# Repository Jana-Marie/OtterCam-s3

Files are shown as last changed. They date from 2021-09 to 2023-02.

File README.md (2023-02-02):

# OtterCam-s3

Open source 1080p60Hz USB & IP camera based on Sochip s3 and OS05A10/OS05A20 (general MIPI CSI IP camera interface).

In the current state the camera does boot and the sensor shows up under linux, however no video or image files have been captured yet, as the sensor driver is currently being written by us. All hardware files are tested in the current revision and are, except for some minor changes, final. Still no waranty as this is an open source project. CAD files have been designed with OpenSCAD and should be final too.

<table>
  <tbody>
    <tr>
      <td>
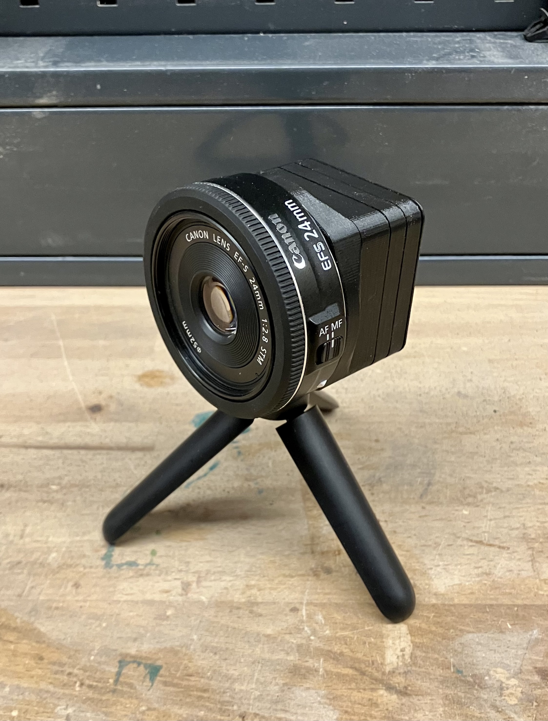
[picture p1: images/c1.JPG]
        
      </td>
      <td>
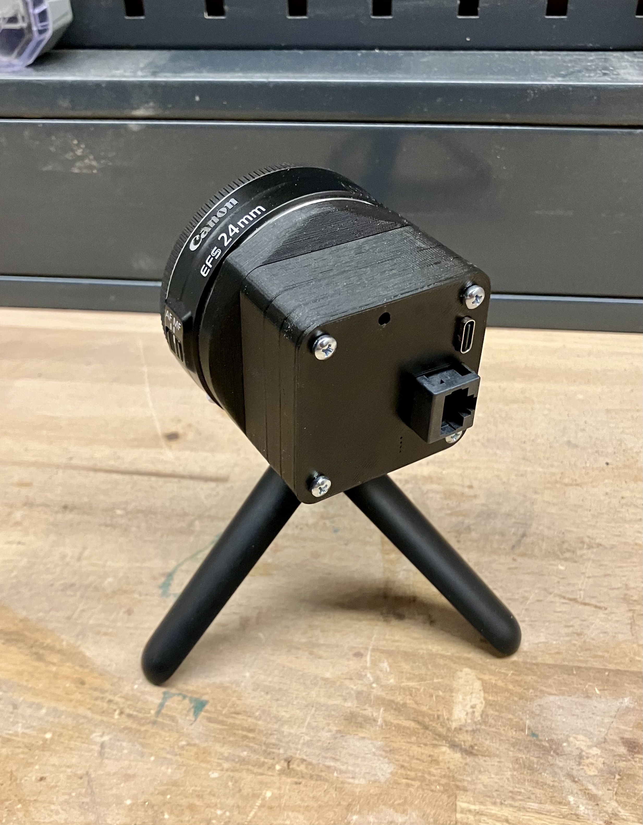
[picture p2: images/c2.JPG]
        
      </td>
    </tr>
    <tr>
      <td colspan="2">
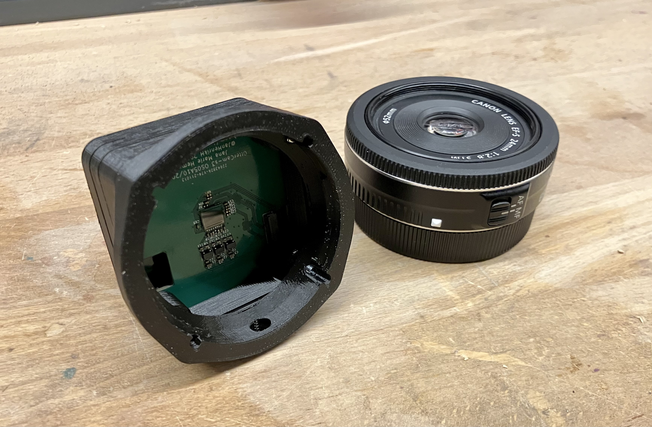
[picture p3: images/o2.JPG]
        
      </td>
    </tr>
    <tr>
      <td>
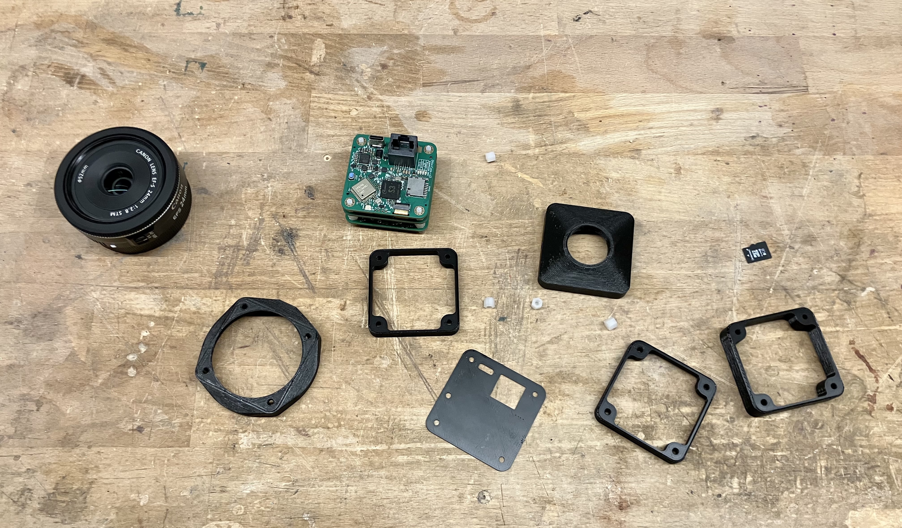
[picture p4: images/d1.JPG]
        
      </td>
      <td>
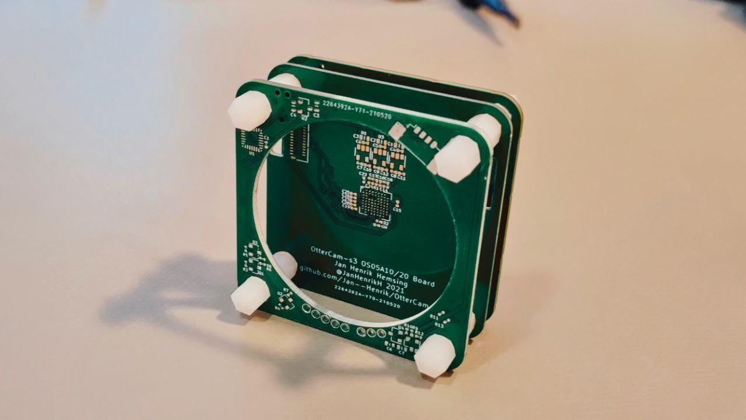
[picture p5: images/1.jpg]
        
      </td>
    </tr>
  </tbody>
</table>

### Todo
 - [ ] Test mipi driver
 - [ ] Build userspace code

### Issues
 - [x] MIPI Lanes Sensor are switched
 - [x] No I2C Pullups

### License

Copyright Jana Marie Hemsing 2023.

This source describes Open Hardware and is licensed under the CERN-OHL-S v2.

You may redistribute and modify this source and make products using it under
the terms of the CERN-OHL-S v2 (https://ohwr.org/cern_ohl_s_v2.txt).

This source is distributed WITHOUT ANY EXPRESS OR IMPLIED WARRANTY,
INCLUDING OF MERCHANTABILITY, SATISFACTORY QUALITY AND FITNESS FOR A
PARTICULAR PURPOSE. Please see the CERN-OHL-S v2 for applicable conditions.

Source location: https://github.com/Jana-Marie/OtterCam-s3

As per CERN-OHL-S v2 section 4, should You produce hardware based on this
source, You must where practicable maintain the Source Location visible
on the external case of the Gizmo or other products you make using this
source.

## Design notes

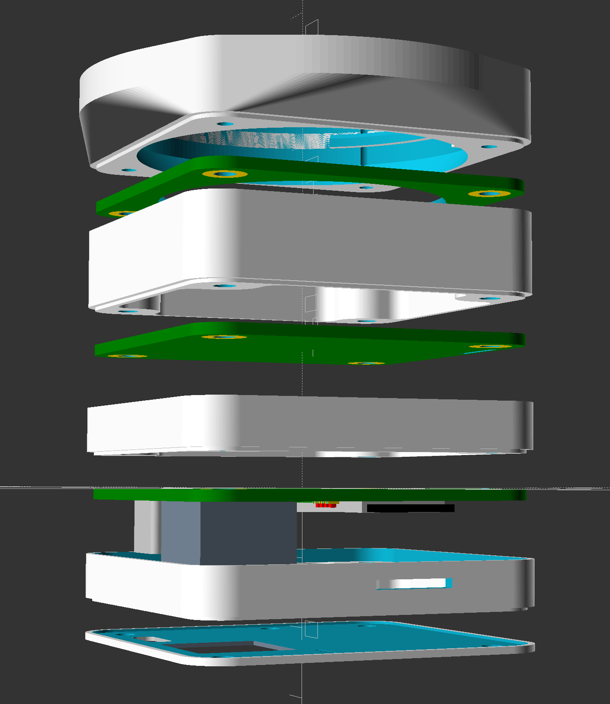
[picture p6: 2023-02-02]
images/render.png

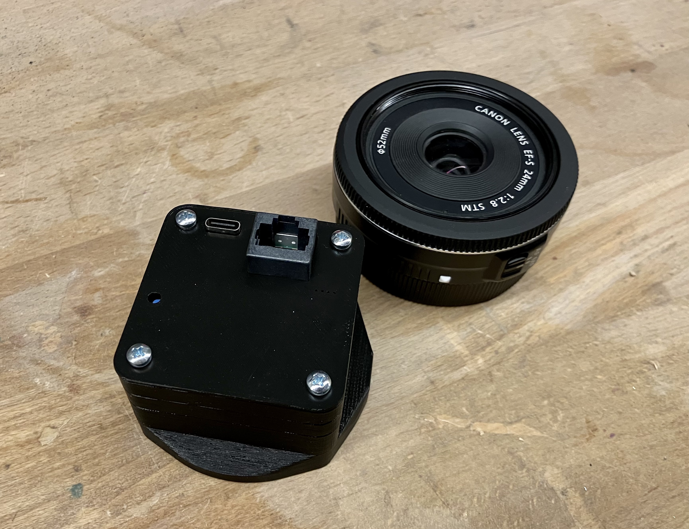
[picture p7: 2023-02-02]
images/o1.JPG

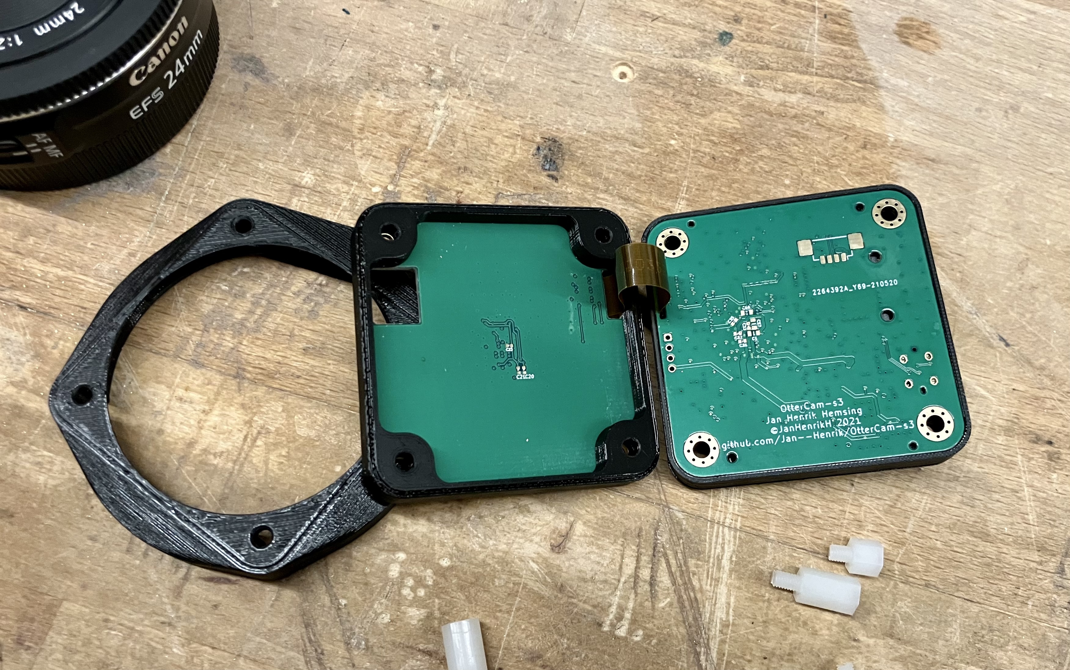
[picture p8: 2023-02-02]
images/d2.JPG

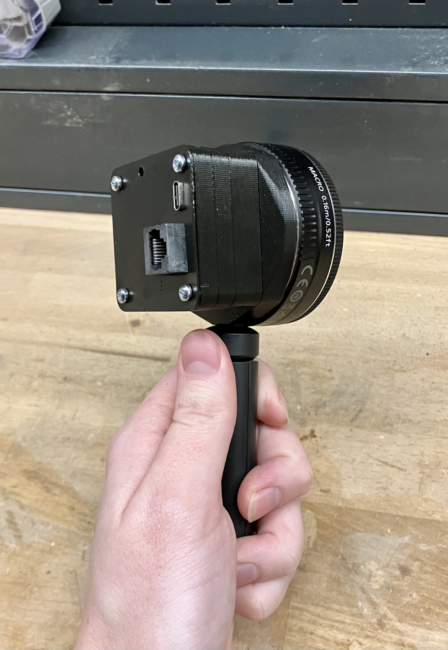
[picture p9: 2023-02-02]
images/c3.JPG

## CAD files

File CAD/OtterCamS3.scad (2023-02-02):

$fn=200;
perim=1;
explode=1;

mount = "efs_mount"; // efs_mount c_mount cs_mount None

if($preview){
    t=1.6;
    if("back_board" && 1){
        translate([0,0,0])back_board(h=t);
    }
    if("sensor_board" && 1){
        translate([0,0,-4.9-t-explode*15])sensor_board(h=t);
    }
    if("shell_b_s" && 1){
        translate([0,0,-4.9-explode*5])shell(h=5,p=perim);
    }

    if("shell_b" && 1){
        translate([0,0,4.9-t-perim-perim/2+explode*10])b_shell(h=4.9,p=perim);
    }
    if("cap_b" && 1){
        translate([0,0,4.9+4.9/2+0.5-perim-perim/2+explode*15])b_cap(h=1,p=perim);
    }
    if(mount == "efs_mount"){
        if("shell_s_l" && 1){
            translate([0,0,-4.9-t-10-explode*20])shell(h=9.9,p=perim);
        }
        if("lens_board" && 1){
            translate([0,0,-4.9-t-10-t-explode*25])lens_board(h=t);
        }
        if("efs_mount" && 1){
            translate([0,0,-4.9-t-9.9-t-t/2-9.9-explode*30])efs_mount();
        }
    }
    if(mount == "c_mount"){
        if("c_mount" && 1){
            translate([0,0,-4.9-t-10-explode*20])c_mount(h=9.9,focus=17.526,sens_h=1,p=perim);
        }
    }
    if(mount == "cs_mount"){
        if("cs_mount" && 1){
            translate([0,0,-2-t-10-explode*20])c_mount(h=7,focus=12.526,sens_h=1,p=perim);
        }
    }
} else {
    c_mount(h=7,focus=12.526,sens_h=1,p=perim);
}

module c_mount(h=10,shoff=0.5,t=1.6,x=49.8,y=49.8,r=4.9,r_d=0.5,p=1,screw=3,focus=17.526,sens_h=1){
    difference(){
        union(){
            difference(){
                union(){
                    for(i = [0:1:3]){
                        // main wall
                       color("white")rotate([0,0,90*i])translate([0,y/2-perim/2,h/2])cube([x-r-r,perim,h],center=true);
                        // screw
                        color("white")rotate([0,0,90*i])hull(){
                            translate([40/2,40/2,0])cylinder(r=r,h=h);
                            translate([x/2-r/2-r,y/2-perim/2,h/2])cube([r,perim,h],center=true);
                            translate([x/2-perim/2,y/2-r/2-r,h/2])cube([perim,r,h],center=true);
                        }
                        // inner diam
                        color("white")rotate([0,0,90*i])
                        difference(){
                            union(){
                                translate([x/2-r-r-r/4,y/2-r/4-perim,h/2])cube([r/2,r/2,h],center=true);
                                translate([x/2-r/4-perim,y/2-r-r-r/4,h/2])cube([r/2,r/2,h],center=true);
                            }
                            union(){
                                translate([x/2-r-r-r/4-r/4,y/2-r/4-perim-r/4,-0.1])cylinder(d=r,h=h+0.2);
                                translate([x/2-r/4-perim-r/4,y/2-r-r-r/4-r/4,-0.1])cylinder(d=r,h=h+0.2);
                            }
                        }
                    }
                    // lenscap
                    color("white")hull(){
                        translate([0,0,-1])minkowski(){
                            cube([x-r-r,y-r-r,3-0.1],center=true);
                            cylinder(r=r+perim,h=0.1);
                        }
                        translate([0,0,h+0.5-focus-sens_h])cylinder(d=30,h=3);
                    }
                }union(){
                    // screw
                    for(i = [-1:2:1]){
                        for(j = [-1:2:1]){
                            translate([i*20,j*20,-0.1])cylinder(d=3.05,h=h+0.2);
                        }
                    }
                    // lenshole
                    translate([0,0,h+0.5-focus-sens_h-0.1])cylinder(d=24.6,h=focus);
                    // lensthread
                    if(!$preview){
                        t_p=0.794;
                        t_h=t_p/2;
                        t_step=12;
                        t_threadstep=t_p/360;
                        translate([0,0,h+0.5-focus-sens_h-0.5])for(i=[0:t_step:360*6]){
                            if(i>0){
                                hull(){
                                    rotate([0,0,i])translate([25.4/2-0.5,0,t_h/2+t_threadstep*i])cube([1.5,0.1,t_h],center=true);
                                    rotate([0,0,i-t_step])translate([25.4/2-0.5,0,t_h/2+t_threadstep*(i-t_step)])cube([1.5,0.1,t_h],center=true);
                                }
                            }
                        }
                    }
                }
            }
            translate([0,0,-shoff])difference() {
                union() {
                    color("white")translate([0,0,h/2-t/2-0.05])minkowski(){
                        cube([x-r-r,y-r-r,h-0.1+t],center=true);
                        cylinder(r=r+perim,h=0.1);
                    }
                }union(){
                    translate([0,0,h/2-t/2-0.1])minkowski(){
                        cube([x-r-r+0.03,y-r-r+0.03,h+t+0.2],center=true);
                        cylinder(r=r,h=0.1);
                    }
                }
            }
            // 1/4"
            c_h=9.5;
            translate([-x/2+(12.7/2),0,-2.75+c_h/2])cube([12.7,12,c_h],center=true);
        }union(){
            // 1/4"
            // https://www.amazon.de/-/en/dp/B09MTS6ZZQ
            rotate([0,90,0])translate([-2.25,0,-x/2-1-0.01])cylinder(d=8,h=12.8); //6.35mm
        }
    }
}

module efs_mount(h=10,shoff=0.5,t=1.6,x=49.8,y=49.8,r=4.9,r_d=0.5,p=1,screw=3){
    difference(){
        union(){
            translate([0,0,h/2+0.5])minkowski(){
                cube([x-r-r,y-r-r,h-0.1],center=true);
                cylinder(r=r,h=0.1);
            }
            hull(){
                hull(){
                    translate([0,0,h/2-0.05])minkowski(){
                        cube([x-r-r,y-r-r,h-0.1],center=true);
                        cylinder(r=r+perim,h=0.1);
                    }
                    translate([0,0,0])cylinder(d=65,h=h/2);
                }
                // mount
                minkowski(){
                    translate([-65/2+1,0,9/2])cube([4-2,12-2,9-2],center=true);
                    sphere(r=1);
                }
            }
        }union(){
            hull(){
                translate([0,0,h])cylinder(d=43.5,h=h/3);
                translate([0,0,-0.1])cylinder(d=54.6,h=6.9+0.2);
            }
            // screw
            for(i = [-1:2:1]){
                for(j = [-1:2:1]){
                    translate([i*20,j*20,-h-0.1])cylinder(d=2.3,h=h*3+0.2);
                }
            }
            // 1/4"
            rotate([0,90,0])translate([-4.5,0,-65/2-1])cylinder(d=5.45,h=6); //6.35mm
            // indicator
            rotate([0,0,112])translate([65/2,0,5/2])rotate([0,0,0])cube([0.3,1.5,1.5],center=true);
        }
    }
    bajonett_angles = [-2, 55.75, 55.75+55.75, 55.75+55.75+54.4, 55.75+55.75+51.4+56.84, 55.75+55.75+51.4+56.84+83.63];
    angle_offset = 0;
    translate([0,0,-0.3])
    difference(){
        union(){
            translate([0,0,1.92])cylinder(d=54.6,h=2.5);
            for(i = [0:2:5]){
                rotate([0,0,bajonett_angles[i]-90])translate([54.6/2-1.4/2,-0.5,2.5/2+2.4+1.92])cube([1.4,1,2.5],center=true);
            }
        }union(){
            translate([0,0,1.92-0.1])cylinder(d=54.6-1.4*2,h=2.5+0.2);
            for(i = [0:2:5]){
                hull(){
                    rotate([0,0,angle_offset+bajonett_angles[i]-90])translate([60/2,0.5,3])cube([20,1,6],center=true);
                    rotate([0,0,angle_offset+bajonett_angles[i+1]-90])translate([60/2,-0.5,3])cube([20,1,6],center=true);
                }
            }
            translate([0,0,-1])cylinder(d1=65,d2=0,h=20);
        }
    }
}
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

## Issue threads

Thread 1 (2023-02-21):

Firmware

EmmanuelP, 2023-02-21:
Hi Jana-Marie,

Interesting project. Do you plan to also open source the firmware ?

I'm the maintainer of the Aravis project, an open source implementation of GiGEVision and USB3Vision protocols. If time permits, I'd like to try to implement the camera part of one of these protocols for the OtterCam.

Emmanuel.

Jana-Marie, 2023-02-22:
Hey Emmanuel! Yea I plan to Open Source everything, include FW and all build sources. It sadly just isn't there yet.
The Linux boots already and shows the sensor on the I2C bus, and has a ready to receive MIPI driver. However userspace software sending the right I2C commands is missing, we are working on that!

I would love to have the OtterCam-s3 (another OtterCam with NDI is in the works. It has the FW, Linux and HDL ready, but is missing the HW. The OtterCam-s3 is a HW sanity check and the cheaper variant of it.) added to aravis! I stumbled across your library just a few days ago, trying to revive a SVS-Vistek GigE cam. Fantastic work! :3

Jana-Marie, 2023-05-04:
Bump: We are still working on it, sorry for all the delay 🙈

Alan01252, 2024-06-12:
As someone about to potentially embark on a similar journey, how did you get on :)?

Jana-Marie, 2024-06-12:
Honestly, we didn't. Didn't yet, although what is that yet worth. I haven't given up on the OtterCamS3, but I also haven't worked on it in a while. We lost all momentum and haven't regained it yet, so I'm afraid there is no good answer to "how did you get on" :/

peteallenm, 2024-06-17:
I'm very interested in this.
I've got some very relevant experience-I've written a mipi driver for S3 with hdzero cameras (drone cameras with mipi csi yuyv output).
I'm looking for better sensors (hdzero is 720/60) and so was looking at these omnivision sensors.
Do you want to collaborate?

Jana-Marie, 2024-06-18:
Hey all and @peteallenm,

Thank you so much for your interest, collaboration would be highly welcome :3

As it seems, we need to tackle the following tasks next:

- write a driver for the OS05A10/A20
- write userspace software
  - something that does the peripheral -> stream transport
  - V4l to I2C for the OS05A10/A20
  - Maybe a web-ui for further configuration

There is actually already a working fork of the OtterCam3, which already addresses the driver + stream issue 🙈 We will try to incorporate it back into the OtterCamS3, leaving us with less and easier issues to work on. https://gregdavill.com/posts/allwinner-s3-videoencoders/

I'm away until mid-July. Your interest motivates me to work on this project again, I will return to it in July and I will try to get it to a working point. I'm not entirely sure how further collaboration works the best, any ideas?

~ Jana

peteallenm, 2024-06-23:
Have you got a datasheet for the OS05A10?
One of the first things with the driver is to set up the (MIPI) bus format, and that is not easy without the datasheet.
I also presume you are using the onboard ISP, so intending to get the sensor to give you what it describes as RGB? I haven't looked into the S3 ISP at all, but understand debayering should be possible, but tuning the ISP for a sensor is out of reach for hobbyists, so the onboard ISP makes a lot of sense.
The datasheet for OS08A20 (same range, different sensor) mentions YUV420p output (which would be ideal), but not anything about specifics of it. The OS05A20 drivers I've seen on github confuse me a little as they seem to be bayer output, which is not ideal, but I've only looked at a couple.
Just FYI I had to fix a load of bugs in the MIPI driver for YUYV formats on S3.

 It's pretty easy to send I2C from userspace... i2cset is your friend.

peteallenm, 2024-06-23:
Oh - you mentioned getting raw images out:
v4l2-ctl --set-fmt-video=width=1280,height=720,pixelformat=NV12 --stream-mmap --stream-count=1 -d /dev/video0 --stream-to=CamOutNV12.raw
Obviously change the video format to suit.

Can you point me to the working fork of ottercam 3? I am pretty interested

Jana-Marie, 2024-07-19:
Thanks! I will try that! I havent gotten around to working on it yet, sorry for that. I'm not sure if the/a working fork is pushed somewhere being honest, I will check

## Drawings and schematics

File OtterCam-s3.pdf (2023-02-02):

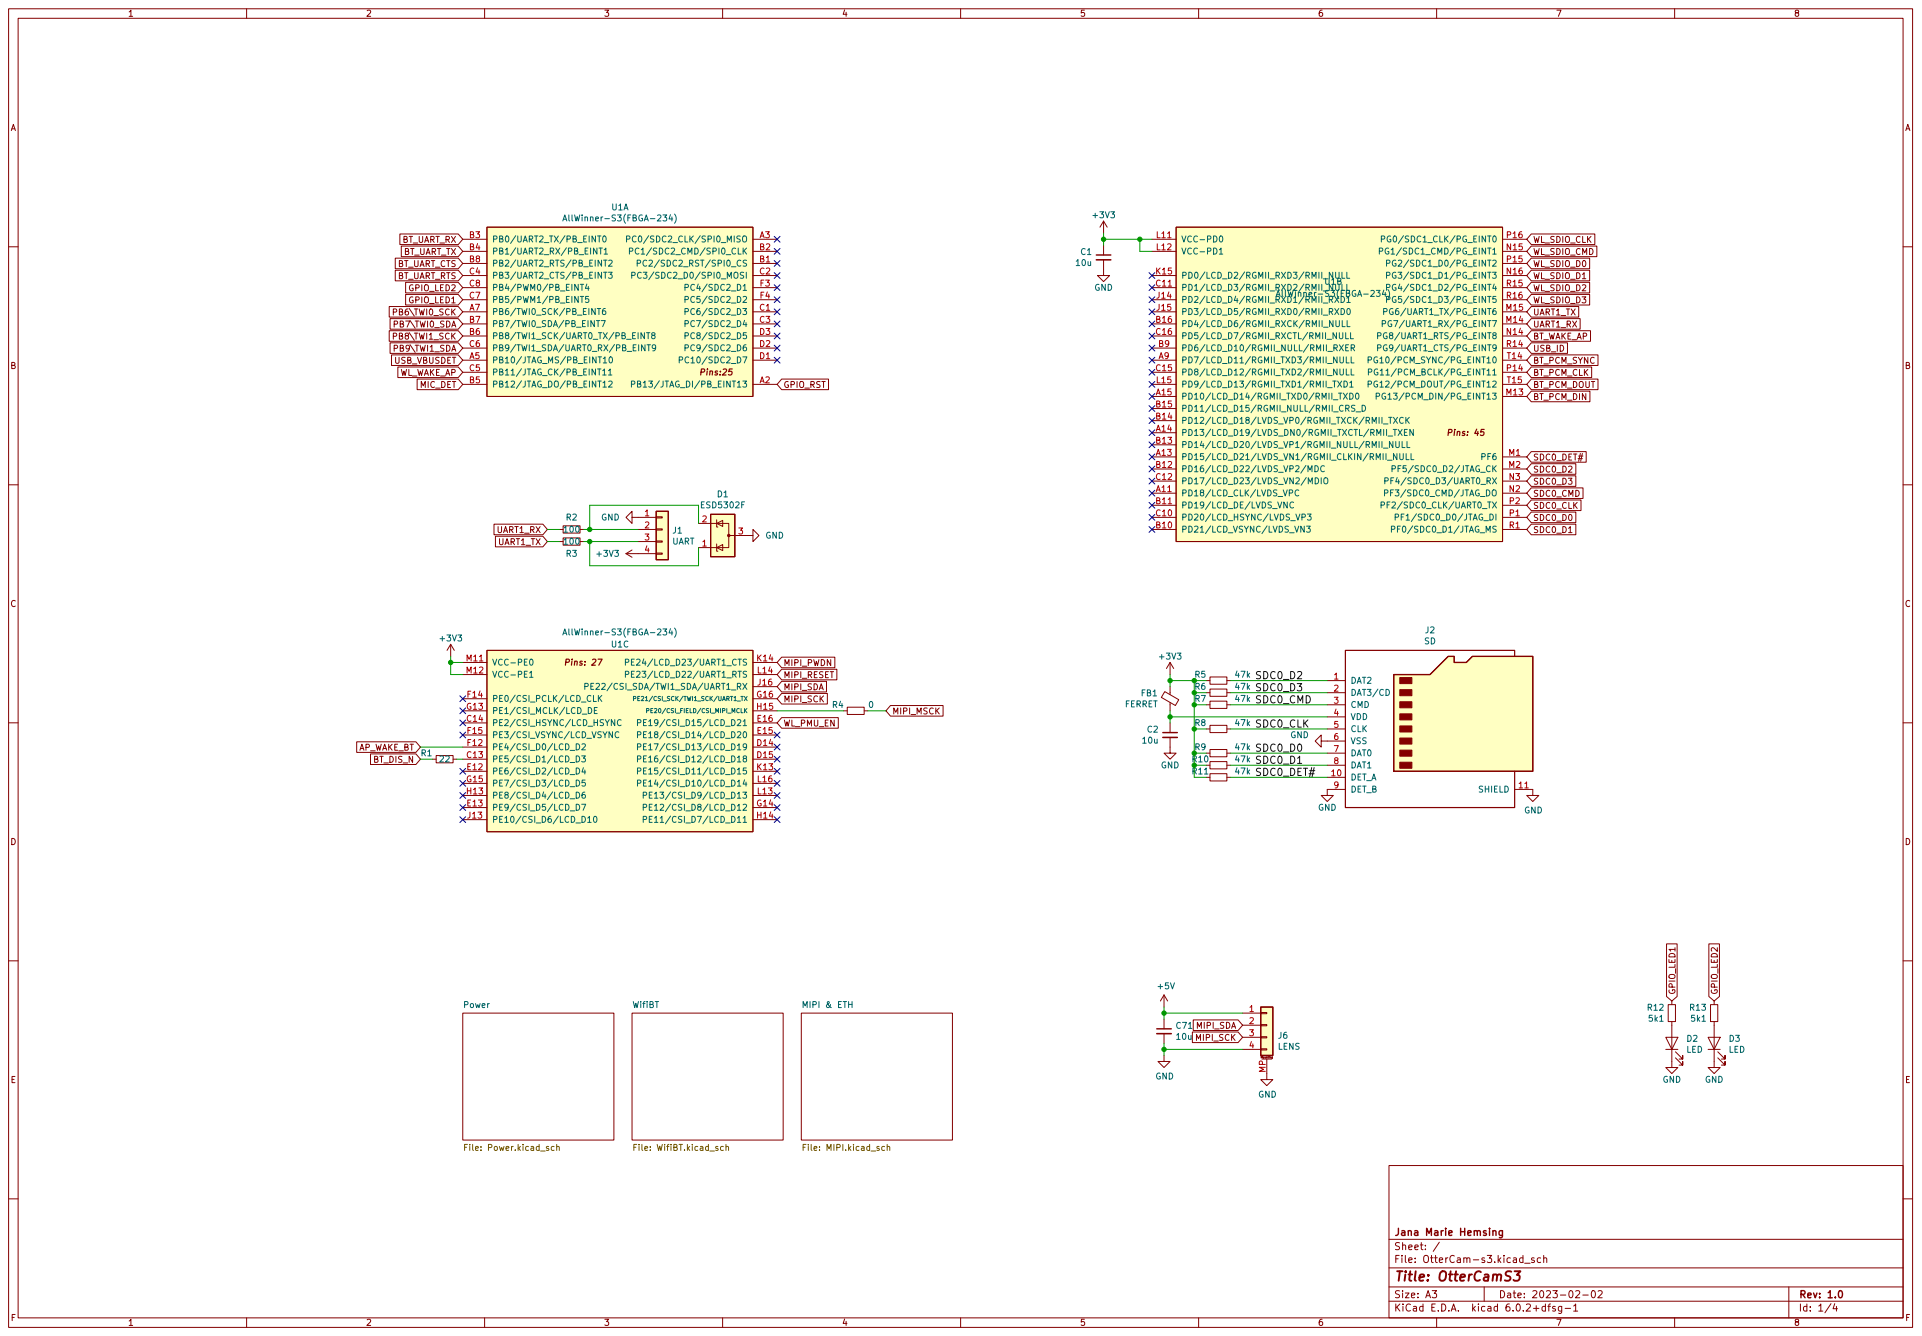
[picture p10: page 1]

File: OtterCam-s3.kicad_sch Sheet: / Jana Marie Hemsing MIPI & ETH

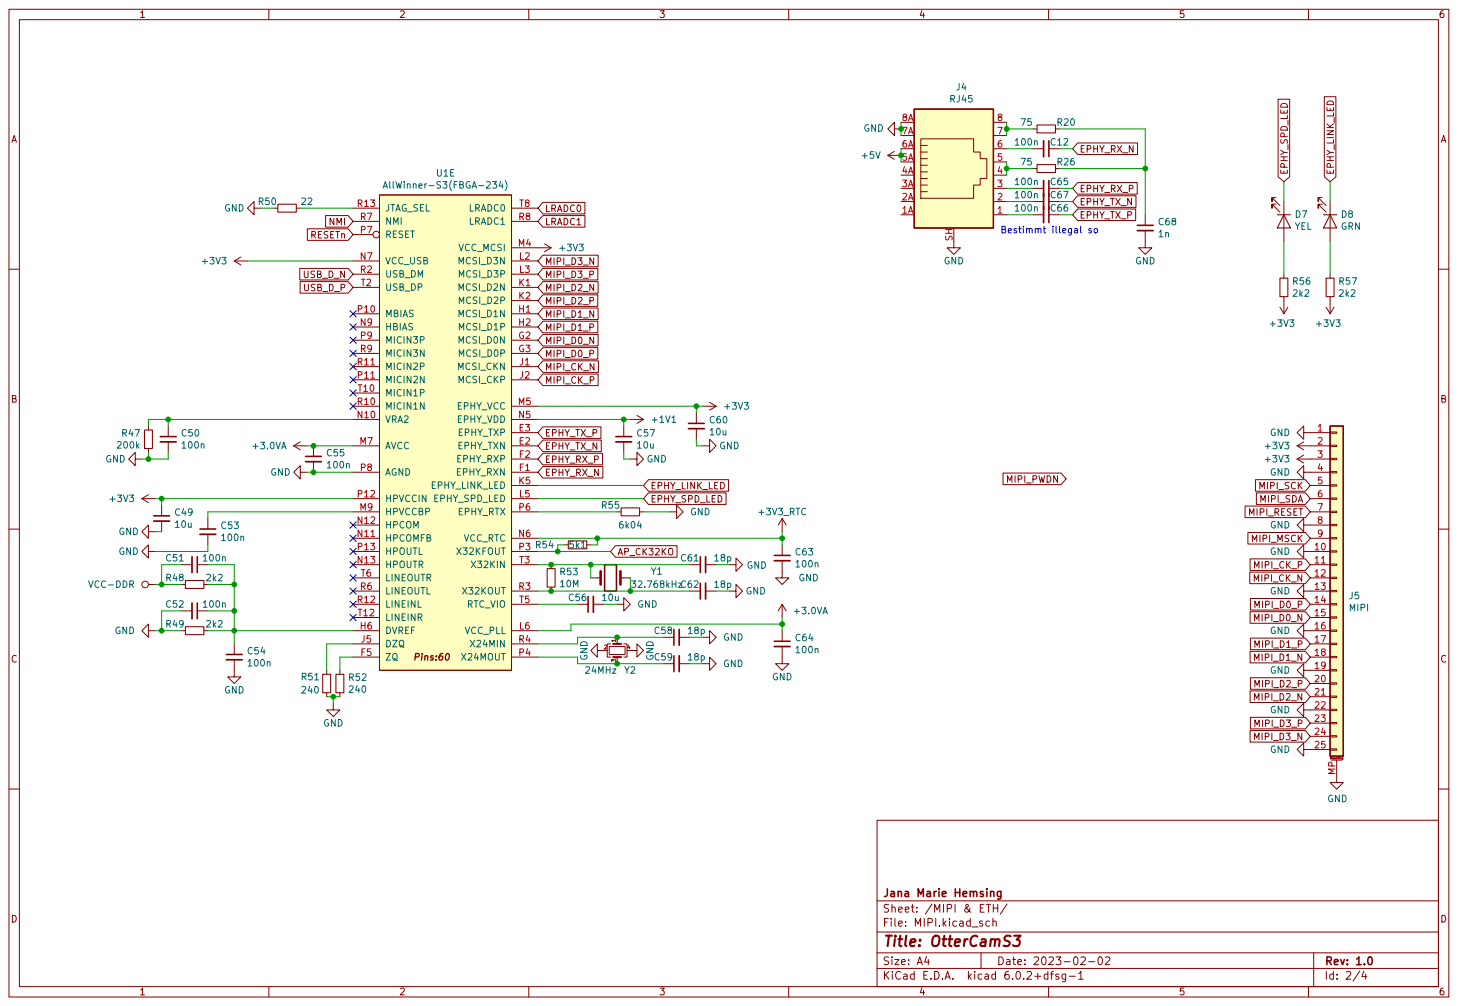
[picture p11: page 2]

File: MIPI.kicad_sch Sheet: /MIPI & ETH/ Jana Marie Hemsing GND

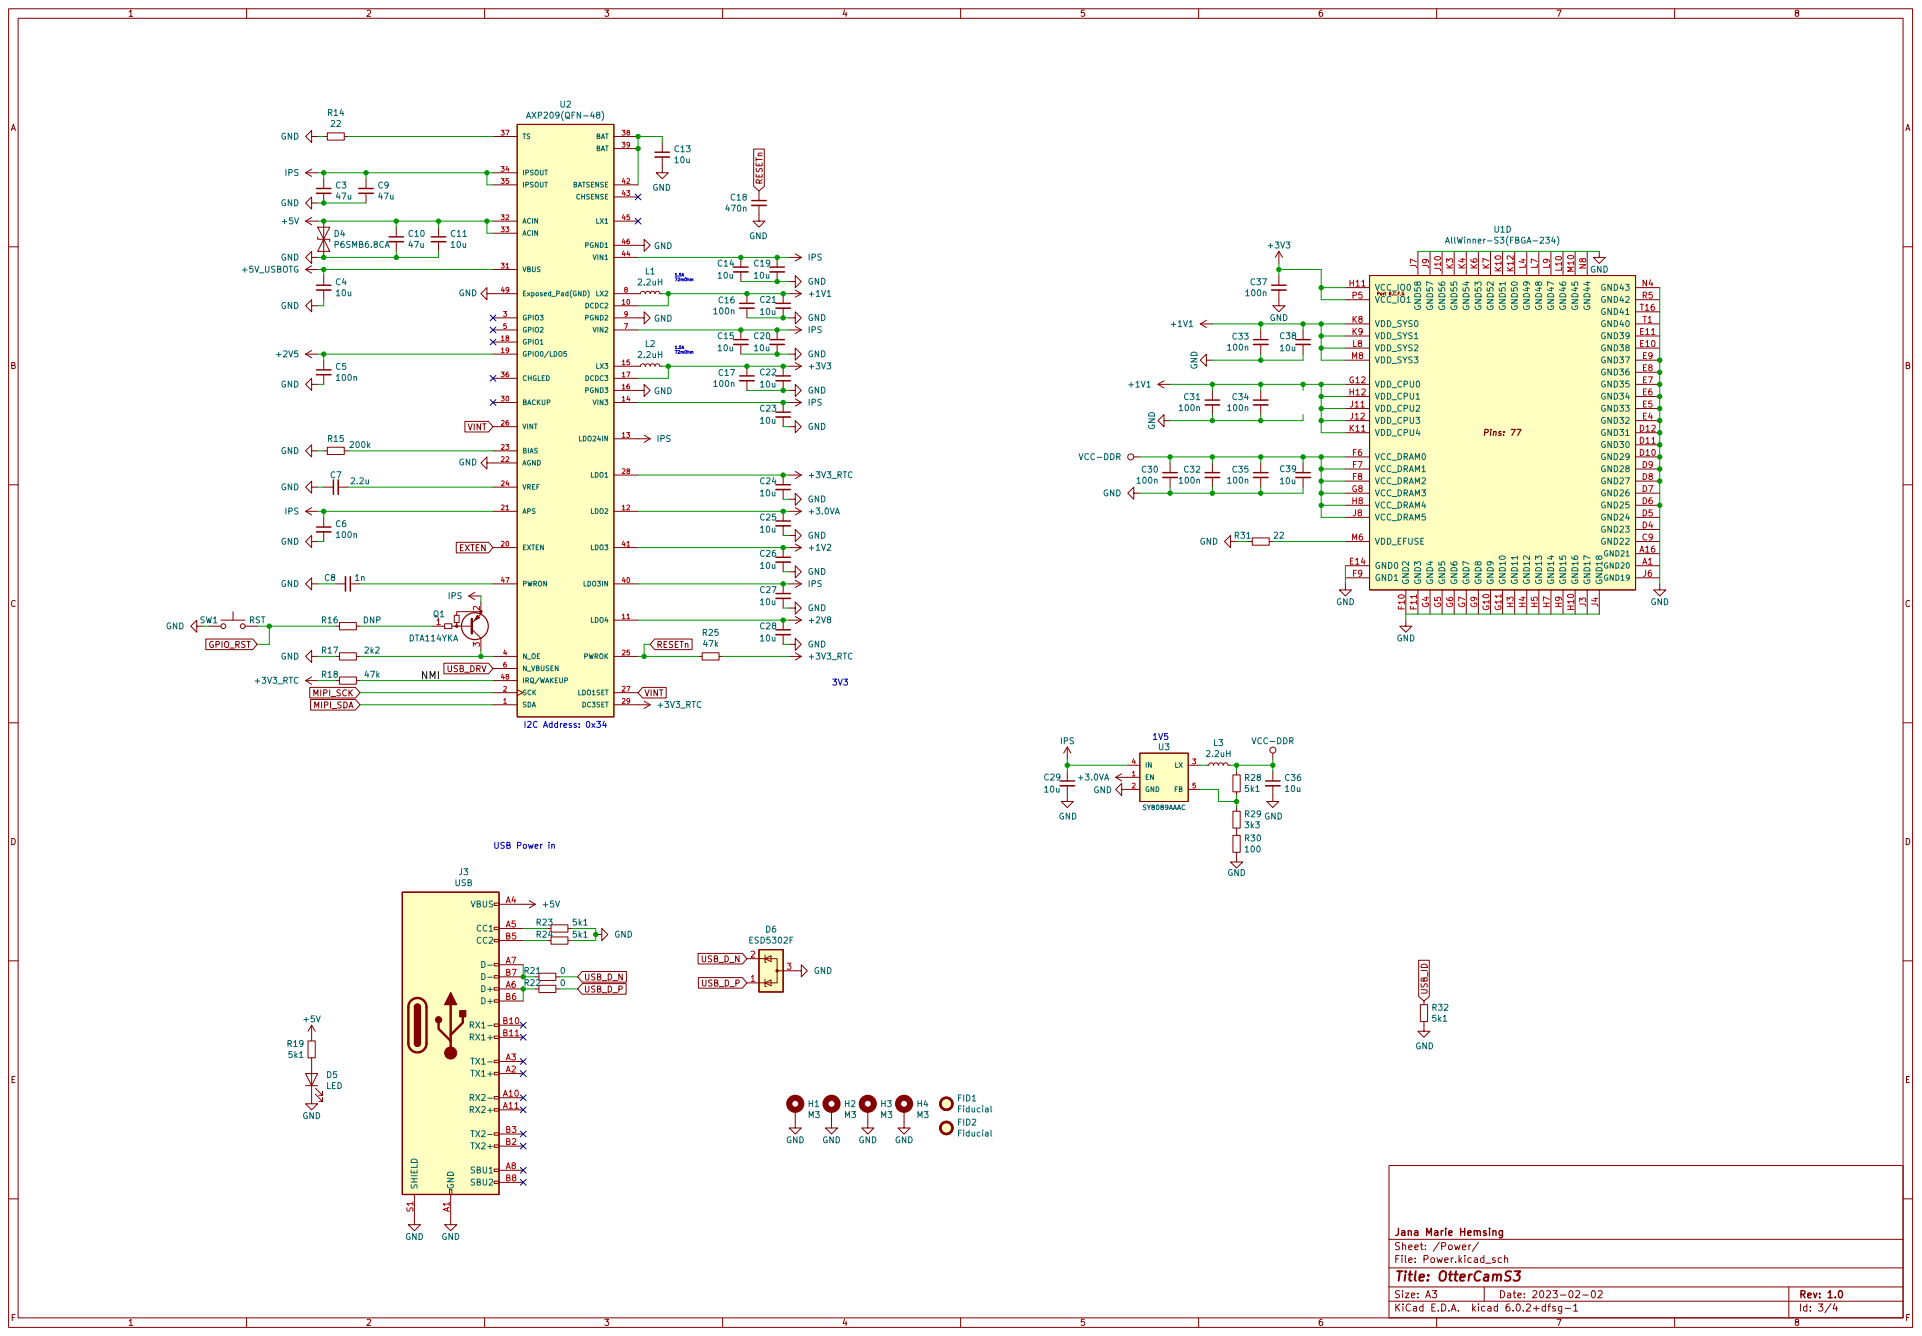
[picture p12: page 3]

I2C Address: 0x34 USB Power in

File: Power.kicad_sch Sheet: /Power/ Jana Marie Hemsing

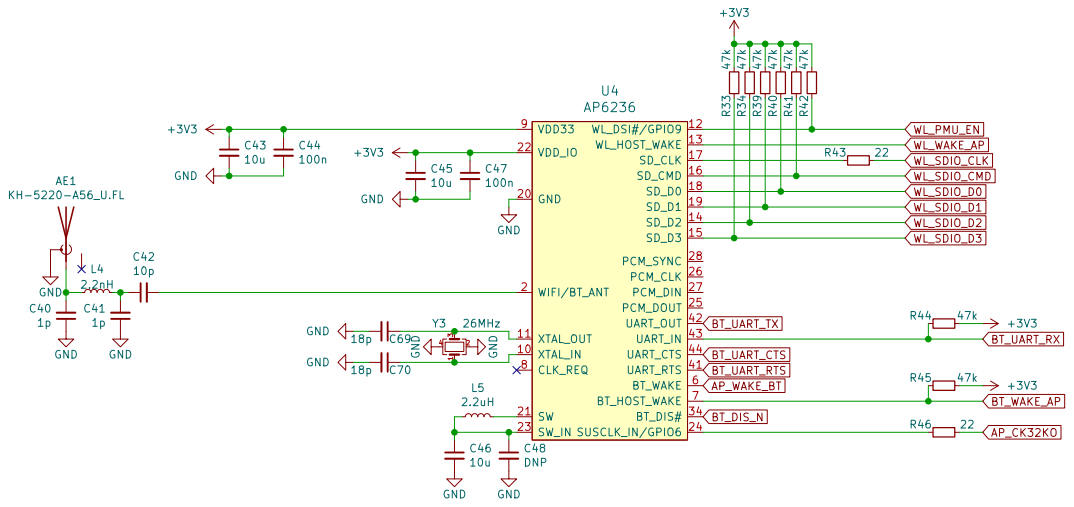
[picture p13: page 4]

File: WifiBT.kicad_sch Sheet: /WifiBT/ Jana Marie Hemsing C42

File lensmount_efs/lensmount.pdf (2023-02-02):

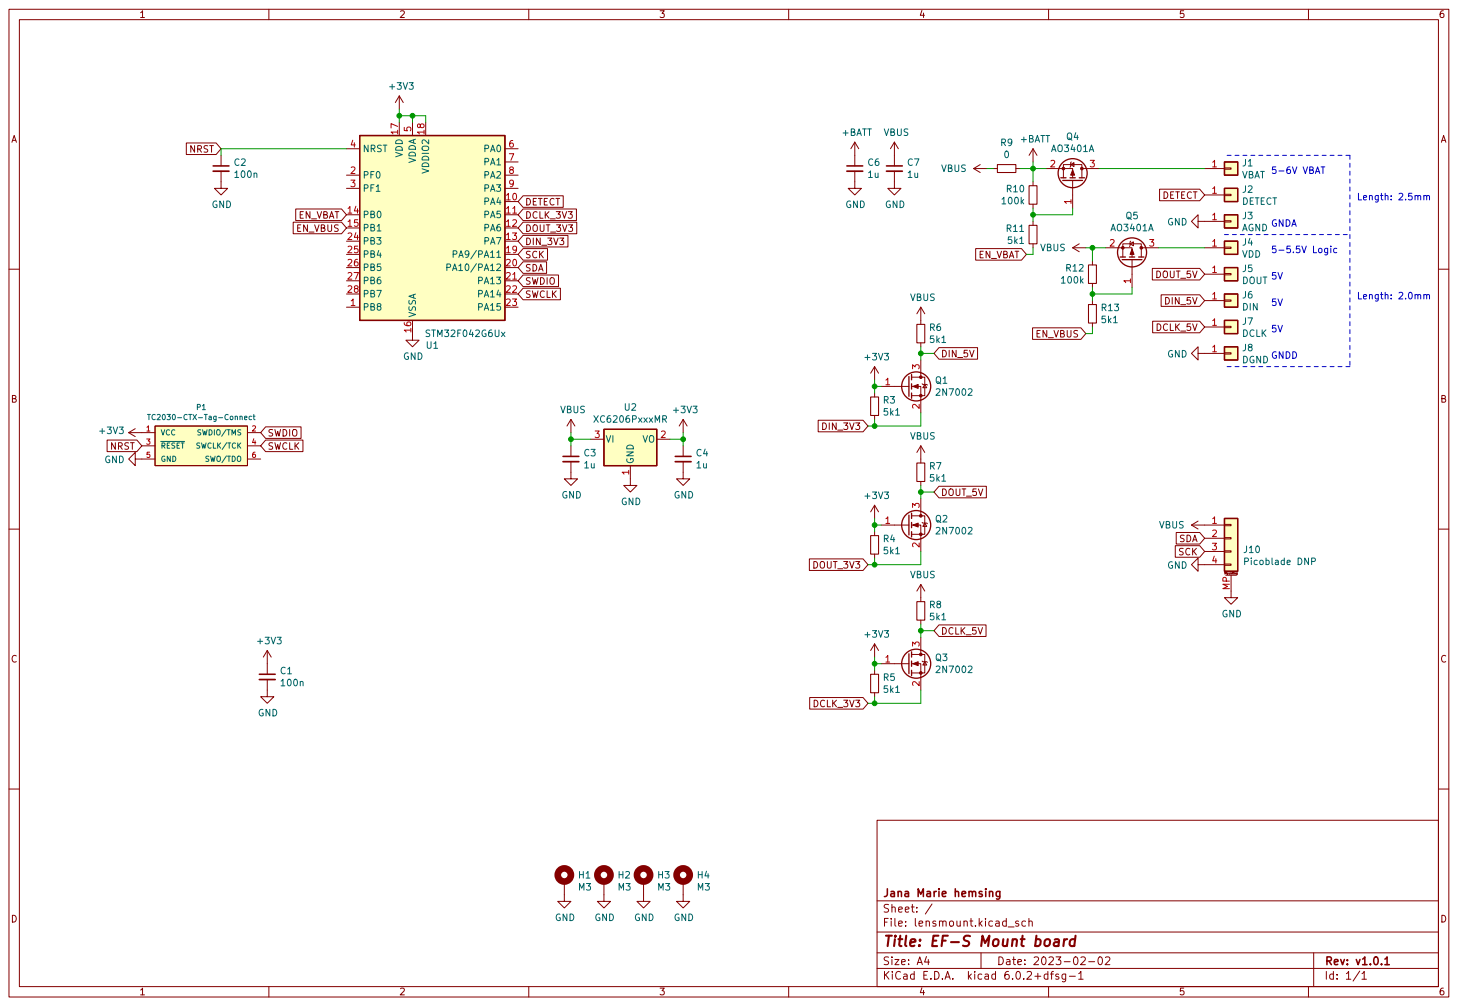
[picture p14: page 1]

1 VO 2 VI 3 U2 XC6206PxxxMR GND GND
VBUSC3

File: lensmount.kicad_sch Sheet: / Jana Marie hemsing C1

Id: 1/1 Title: EF-S Mount board

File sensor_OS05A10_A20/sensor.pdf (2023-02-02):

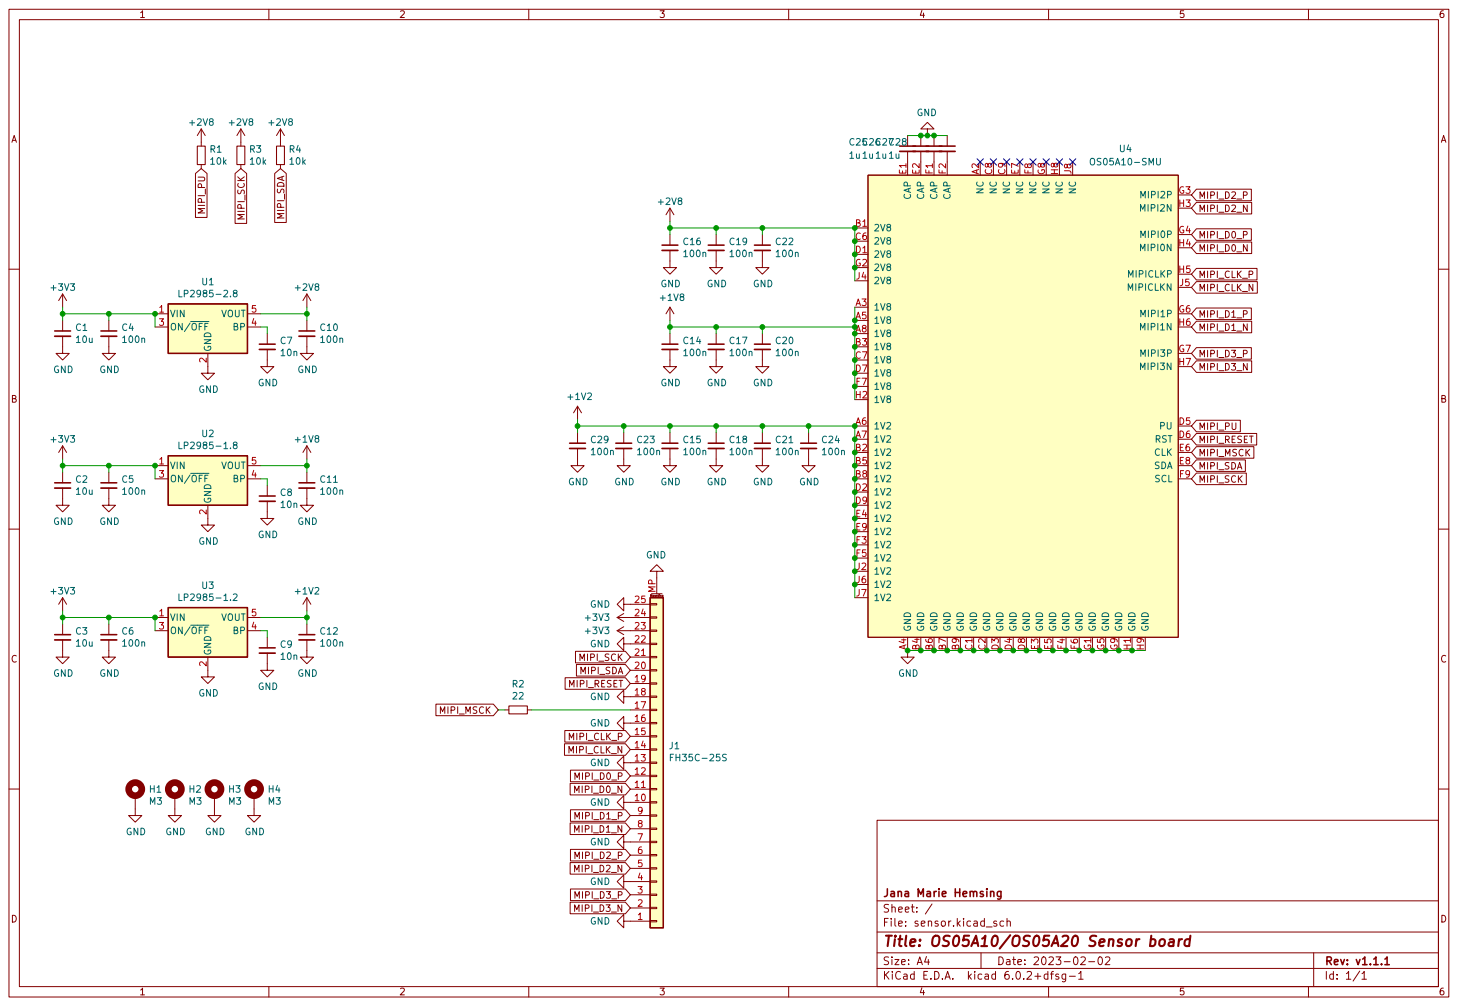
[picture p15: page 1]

File: sensor.kicad_sch Sheet: / Jana Marie Hemsing

Id: 1/1 Title: OS05A10/OS05A20 Sensor board

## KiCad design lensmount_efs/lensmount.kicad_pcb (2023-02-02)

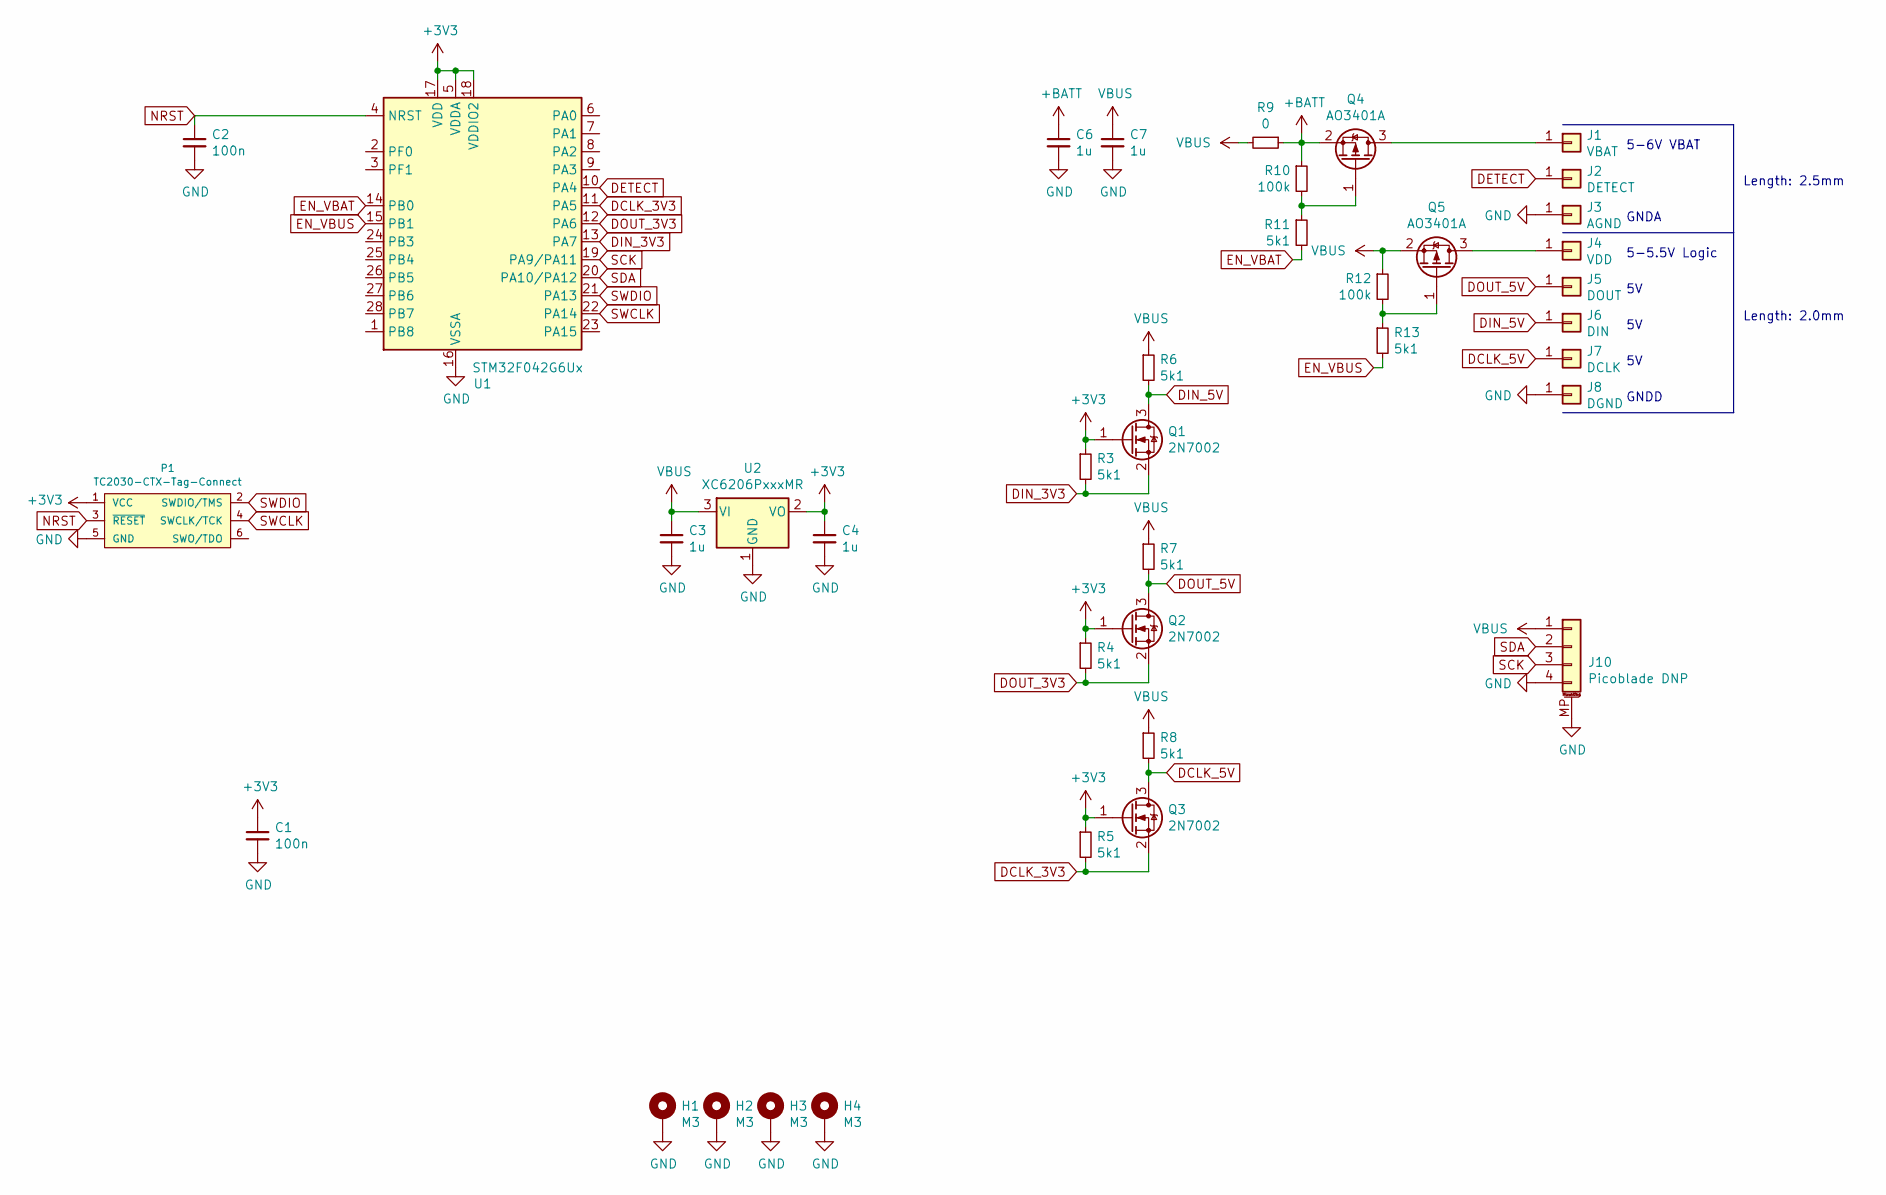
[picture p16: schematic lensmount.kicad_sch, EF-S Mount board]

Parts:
C1, C2: 100n; C_0402
C3, C4, C6, C7: 1u; C_0603
H1, H2, H3, H4: M3; MountingHole_3mm_Pad_Via
J1: VBAT; PH-MVF-5365; Mouser 581-709150001025006
J2: DETECT; PH-MVF-5365; Mouser 581-709150001025006
J3: AGND; PH-MVF-5365; Mouser 581-709150001025006
J4: VDD; PH-MVF-5365; Mouser 581-709150001020006
J5: DOUT; PH-MVF-5365; Mouser 581-709150001020006
J6: DIN; PH-MVF-5365; Mouser 581-709150001020006
J7: DCLK; PH-MVF-5365; Mouser 581-709150001020006
J8: DGND; PH-MVF-5365; Mouser 581-709150001020006
J10: Picoblade DNP; Molex_PicoBlade_53398-0471_1x04-1MP_P1.25mm_Vertical
P1: TC2030-CTX-Tag-Connect; TC2030
Q1, Q2, Q3: 2N7002; SOT-23
Q4, Q5: AO3401A; SOT-23
R3, R4, R5, R6, R7, R8, R11, R13: 5k1; R_0402
R9: 0; R_0402
R10, R12: 100k; R_0402
U1: STM32F042G6Ux; QFN-28_4x4mm_P0.5mm
U2: XC6206PxxxMR; SOT-23

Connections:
+3V3: C1.1, C4.1, P1.1 (VCC), Q1.1 (G), Q2.1 (G), Q3.1 (G), R3.1, R4.1, R5.1, U1.5 (VDDA), U1.17 (VDD), U1.18 (VDDIO2), U2.2 (VO)
+BATT: C6.1, Q4.2 (S), R9.1, R10.1
DCLK_3V3: Q3.2 (S), R5.2, U1.11 (PA5)
DCLK_5V: J7.1, Q3.3 (D), R8.2
DETECT: J2.1, U1.10 (PA4)
DIN_3V3: Q1.2 (S), R3.2, U1.13 (PA7)
DIN_5V: J6.1, Q1.3 (D), R6.2
DOUT_3V3: Q2.2 (S), R4.2, U1.12 (PA6)
DOUT_5V: J5.1, Q2.3 (D), R7.2
EN_VBAT: R11.2, U1.14 (PB0)
EN_VBUS: R13.2, U1.15 (PB1)
GND: C1.2, C2.2, C3.2, C4.2, C6.2, C7.2, H1.1, H2.1, H3.1, H4.1, J3.1, J8.1, J10.4, J10.MP (MountPin), P1.5 (GND), U1.16 (VSSA), U2.1 (GND)
NRST: C2.1, P1.3 (~RESET), U1.4 (NRST)
unnamed: J1.1, Q4.3 (D)
unnamed: J4.1, Q5.3 (D)
unnamed: Q4.1 (G), R10.2, R11.1
unnamed: Q5.1 (G), R12.2, R13.1
SCK: J10.3, U1.19 (PA9/PA11)
SDA: J10.2, U1.20 (PA10/PA12)
SWCLK: P1.4 (SWCLK/TCK), U1.22 (PA14)
SWDIO: P1.2 (SWDIO/TMS), U1.21 (PA13)
VBUS: C3.1, C7.1, J10.1, Q5.2 (S), R6.1, R7.1, R8.1, R9.2, R12.1, U2.3 (VI)

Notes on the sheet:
GNDD
5-6V VBAT
Length: 2.5mm
5-5.5V Logic
GNDA
Length: 2.0mm

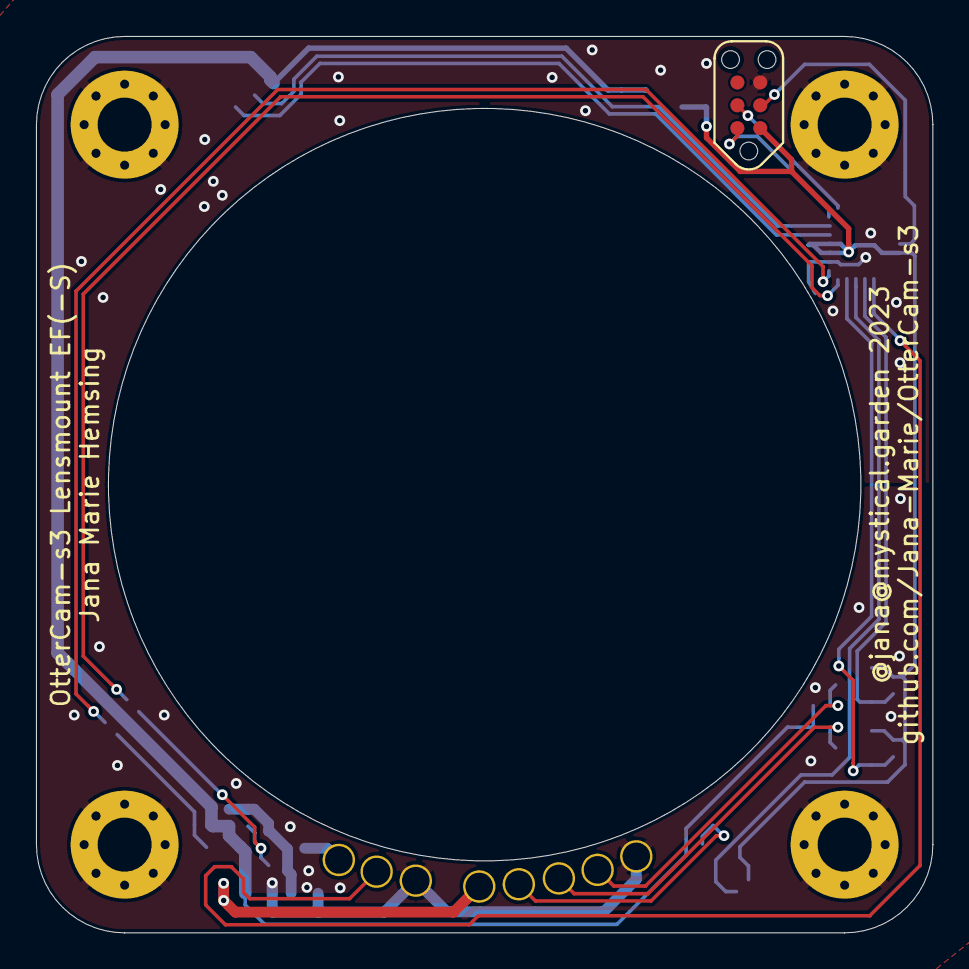
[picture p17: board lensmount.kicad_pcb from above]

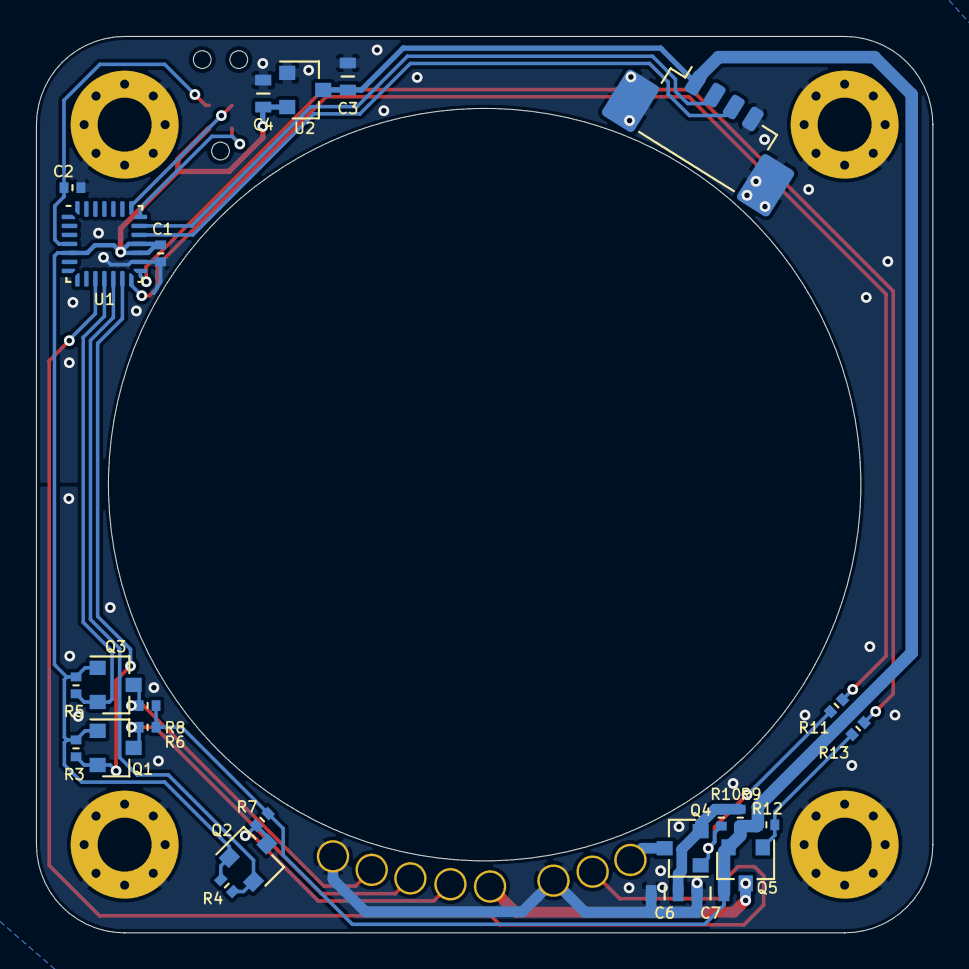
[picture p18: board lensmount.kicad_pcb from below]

Board: 2 copper layers, 49.8 x 49.8 mm, 38 parts (25 on the bottom side), 22 nets.

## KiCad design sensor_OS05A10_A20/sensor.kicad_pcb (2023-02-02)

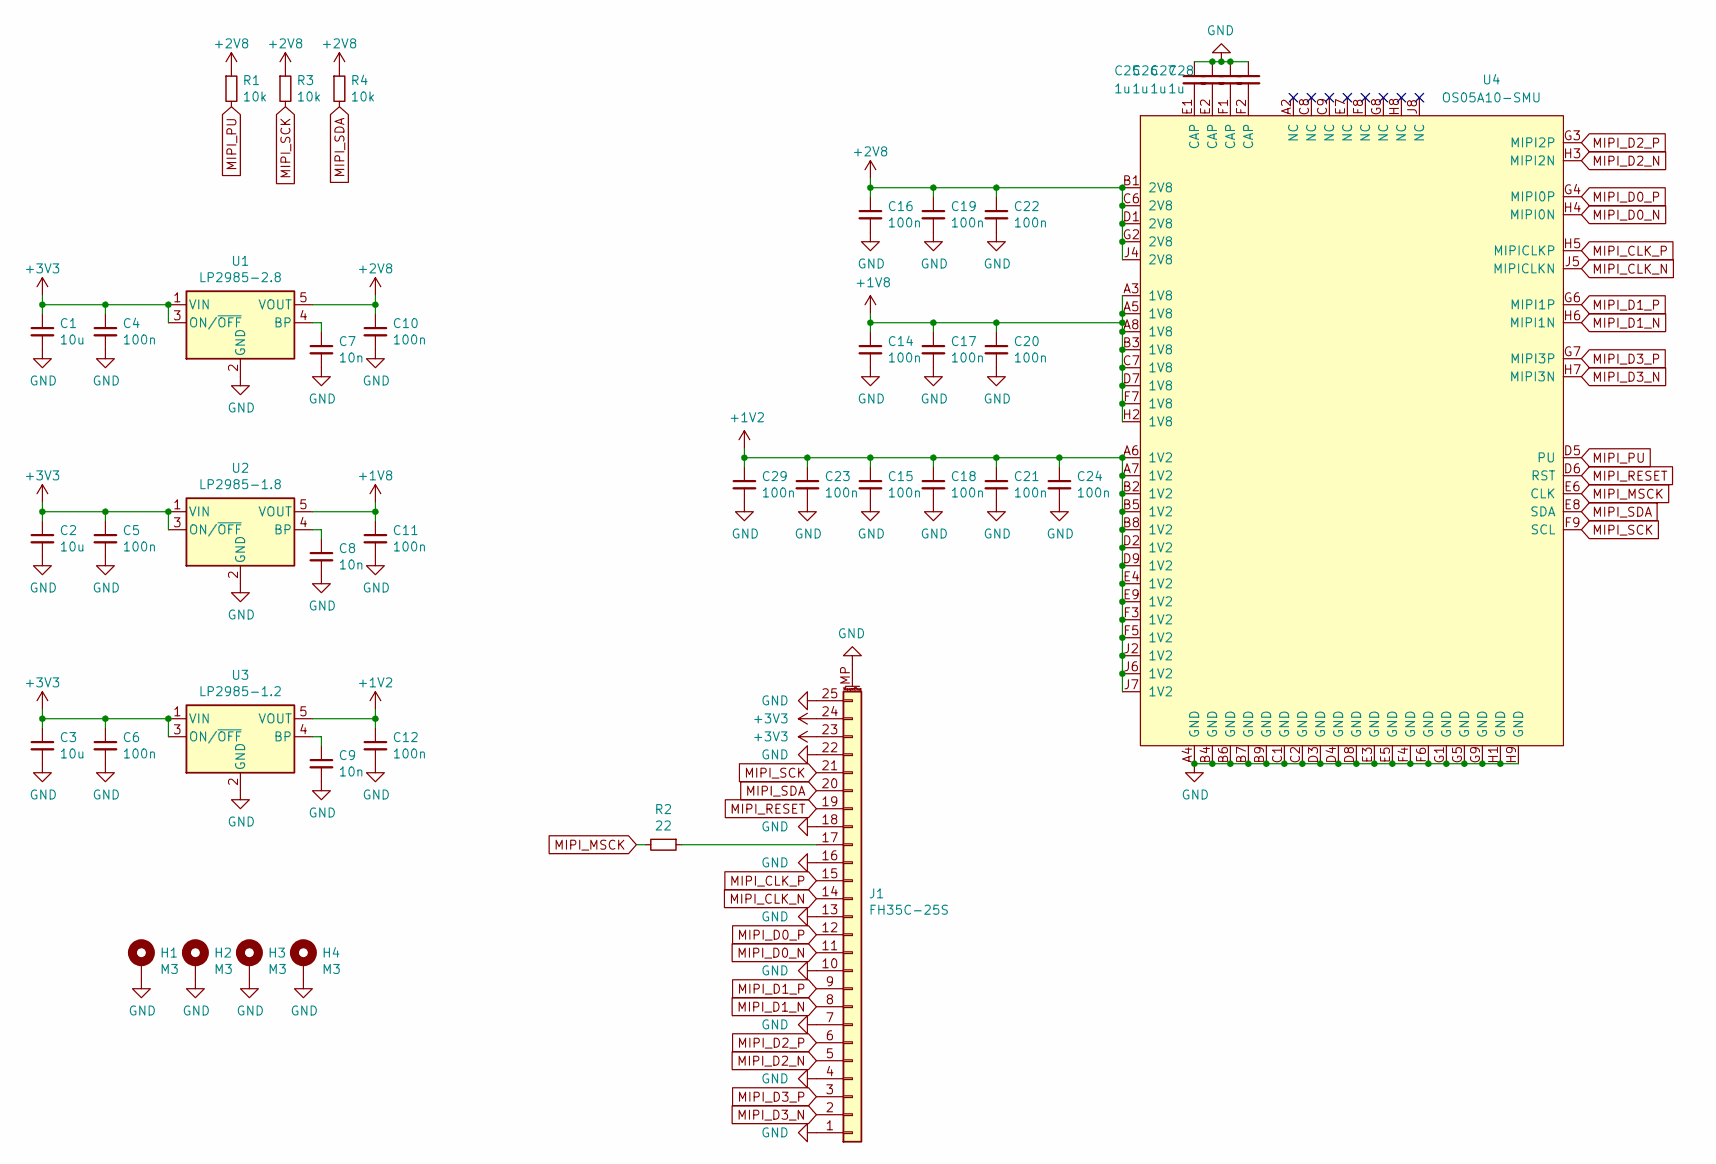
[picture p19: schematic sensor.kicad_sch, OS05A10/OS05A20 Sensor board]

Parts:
C1, C2, C3: 10u; C_0603
C4, C5, C6, C10, C11, C12, C14, C15, C16, C17, C18, C19, C20, C21, C22, C23, C24, C29: 100n; C_0402
C7, C8, C9: 10n; C_0402
C25, C26, C27, C28: 1u; C_0402
H1, H2, H3, H4: M3; MountingHole_3mm_Pad_Via
J1: FH35C-25S
R1, R3, R4: 10k; R_0402
R2: 22; R_0402
U1: LP2985-2.8; SOT-23-5
U2: LP2985-1.8; SOT-23-5
U3: LP2985-1.2; SOT-23-5
U4: OS05A10-SMU; OS05A10

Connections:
+1V2: C12.1, C15.1, C18.1, C21.1, C23.1, C24.1, C29.1, U3.5 (VOUT), U4.A6 (1V2), U4.A7 (1V2), U4.B2 (1V2), U4.B5 (1V2), U4.B8 (1V2), U4.D2 (1V2), U4.D9 (1V2), U4.E4 (1V2), U4.E9 (1V2), U4.F3 (1V2), U4.F5 (1V2), U4.J2 (1V2), U4.J6 (1V2), U4.J7 (1V2)
+1V8: C11.1, C14.1, C17.1, C20.1, U2.5 (VOUT), U4.A3 (1V8), U4.A5 (1V8), U4.A8 (1V8), U4.B3 (1V8), U4.C7 (1V8), U4.D7 (1V8), U4.F7 (1V8), U4.H2 (1V8)
+2V8: C10.1, C16.1, C19.1, C22.1, R1.1, R3.1, R4.1, U1.5 (VOUT), U4.B1 (2V8), U4.C6 (2V8), U4.D1 (2V8), U4.G2 (2V8), U4.J4 (2V8)
+3V3: C1.1, C2.1, C3.1, C4.1, C5.1, C6.1, J1.23, J1.24, U1.1 (VIN), U1.3 (ON/~OFF), U2.1 (VIN), U2.3 (ON/~OFF), U3.1 (VIN), U3.3 (ON/~OFF)
GND: C1.2, C2.2, C3.2, C4.2, C5.2, C6.2, C7.2, C8.2, C9.2, C10.2, C11.2, C12.2, C14.2, C15.2, C16.2, C17.2, C18.2, C19.2, C20.2, C21.2, C22.2, C23.2, C24.2, C25.1, C26.1, C27.1, C28.1, C29.2, H1.1, H2.1, H3.1, H4.1, J1.1, J1.4, J1.7, J1.10, J1.13, J1.16, J1.18, J1.22, J1.25, J1.MP (MountPin), U1.2 (GND), U2.2 (GND), U3.2 (GND), U4.A4 (GND), U4.B4 (GND), U4.B6 (GND), U4.B7 (GND), U4.B9 (GND), U4.C1 (GND), U4.C2 (GND), U4.D3 (GND), U4.D4 (GND), U4.D8 (GND), U4.E3 (GND), U4.E5 (GND), U4.F4 (GND), U4.F6 (GND), U4.G1 (GND), U4.G5 (GND), U4.G9 (GND), U4.H1 (GND), U4.H9 (GND)
MIPI_CLK_N: J1.14, U4.J5 (MIPICLKN)
MIPI_CLK_P: J1.15, U4.H5 (MIPICLKP)
MIPI_D0_N: J1.11, U4.H4 (MIPI0N)
MIPI_D0_P: J1.12, U4.G4 (MIPI0P)
MIPI_D1_N: J1.8, U4.H6 (MIPI1N)
MIPI_D1_P: J1.9, U4.G6 (MIPI1P)
MIPI_D2_N: J1.5, U4.H3 (MIPI2N)
MIPI_D2_P: J1.6, U4.G3 (MIPI2P)
MIPI_D3_N: J1.2, U4.H7 (MIPI3N)
MIPI_D3_P: J1.3, U4.G7 (MIPI3P)
MIPI_MSCK: R2.2, U4.E6 (CLK)
MIPI_PU: R1.2, U4.D5 (PU)
MIPI_RESET: J1.19, U4.D6 (RST)
MIPI_SCK: J1.21, R3.2, U4.F9 (SCL)
MIPI_SDA: J1.20, R4.2, U4.E8 (SDA)
unnamed: C7.1, U1.4 (BP)
unnamed: C8.1, U2.4 (BP)
unnamed: C9.1, U3.4 (BP)
unnamed: C25.2, U4.E1 (CAP)
unnamed: C26.2, U4.E2 (CAP)
unnamed: C27.2, U4.F1 (CAP)
unnamed: C28.2, U4.F2 (CAP)
unnamed: J1.17, R2.1

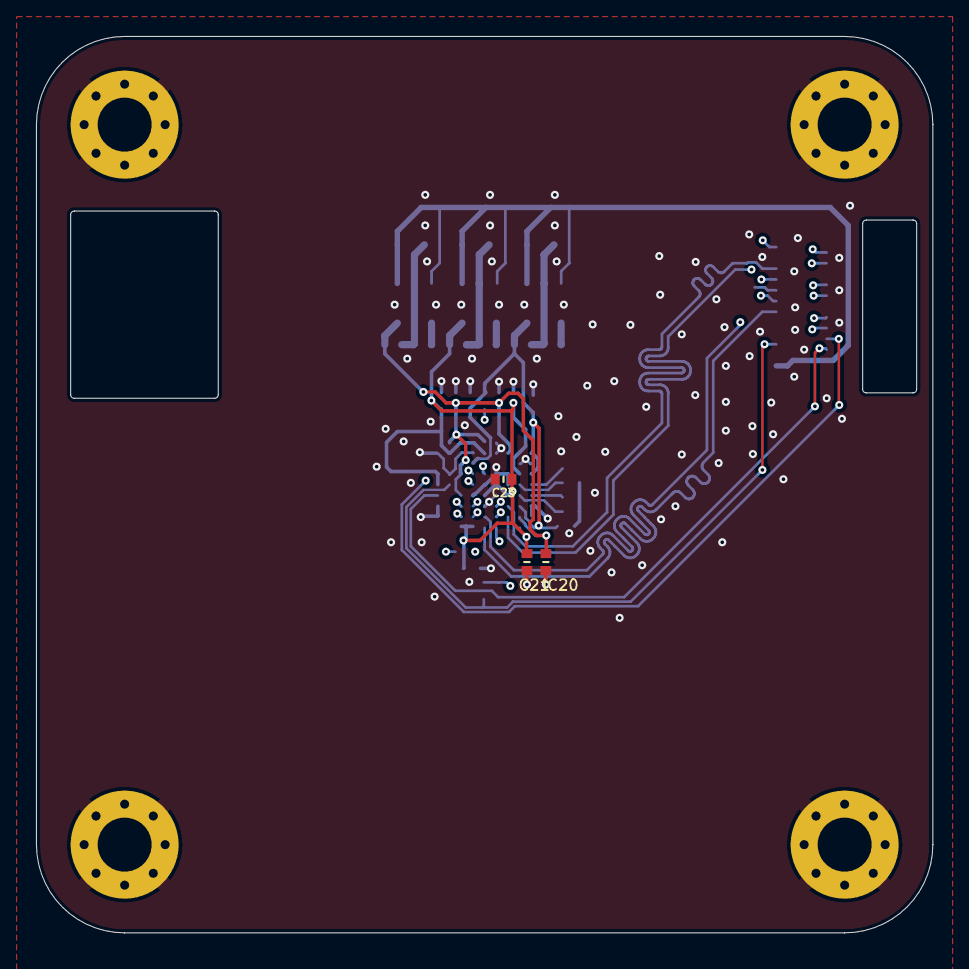
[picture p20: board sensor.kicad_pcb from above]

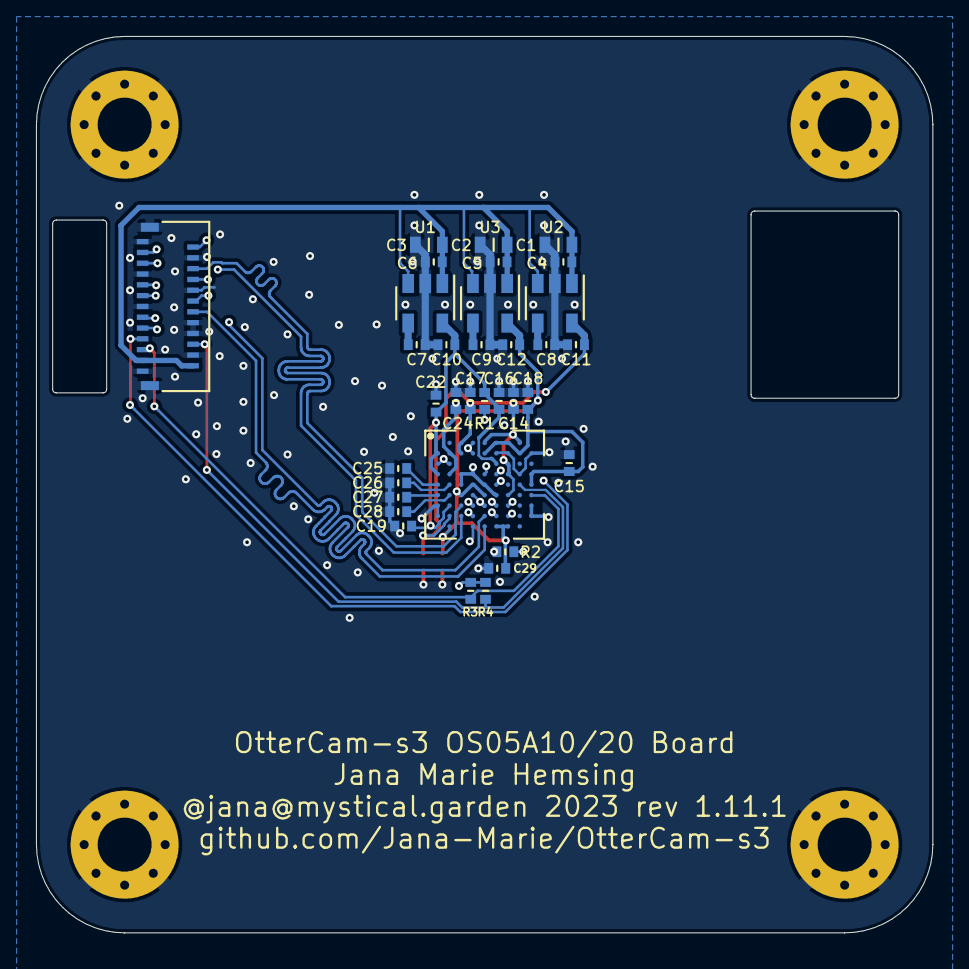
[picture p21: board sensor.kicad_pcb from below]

Board: 4 copper layers, 49.8 x 49.8 mm, 41 parts (38 on the bottom side), 28 nets.

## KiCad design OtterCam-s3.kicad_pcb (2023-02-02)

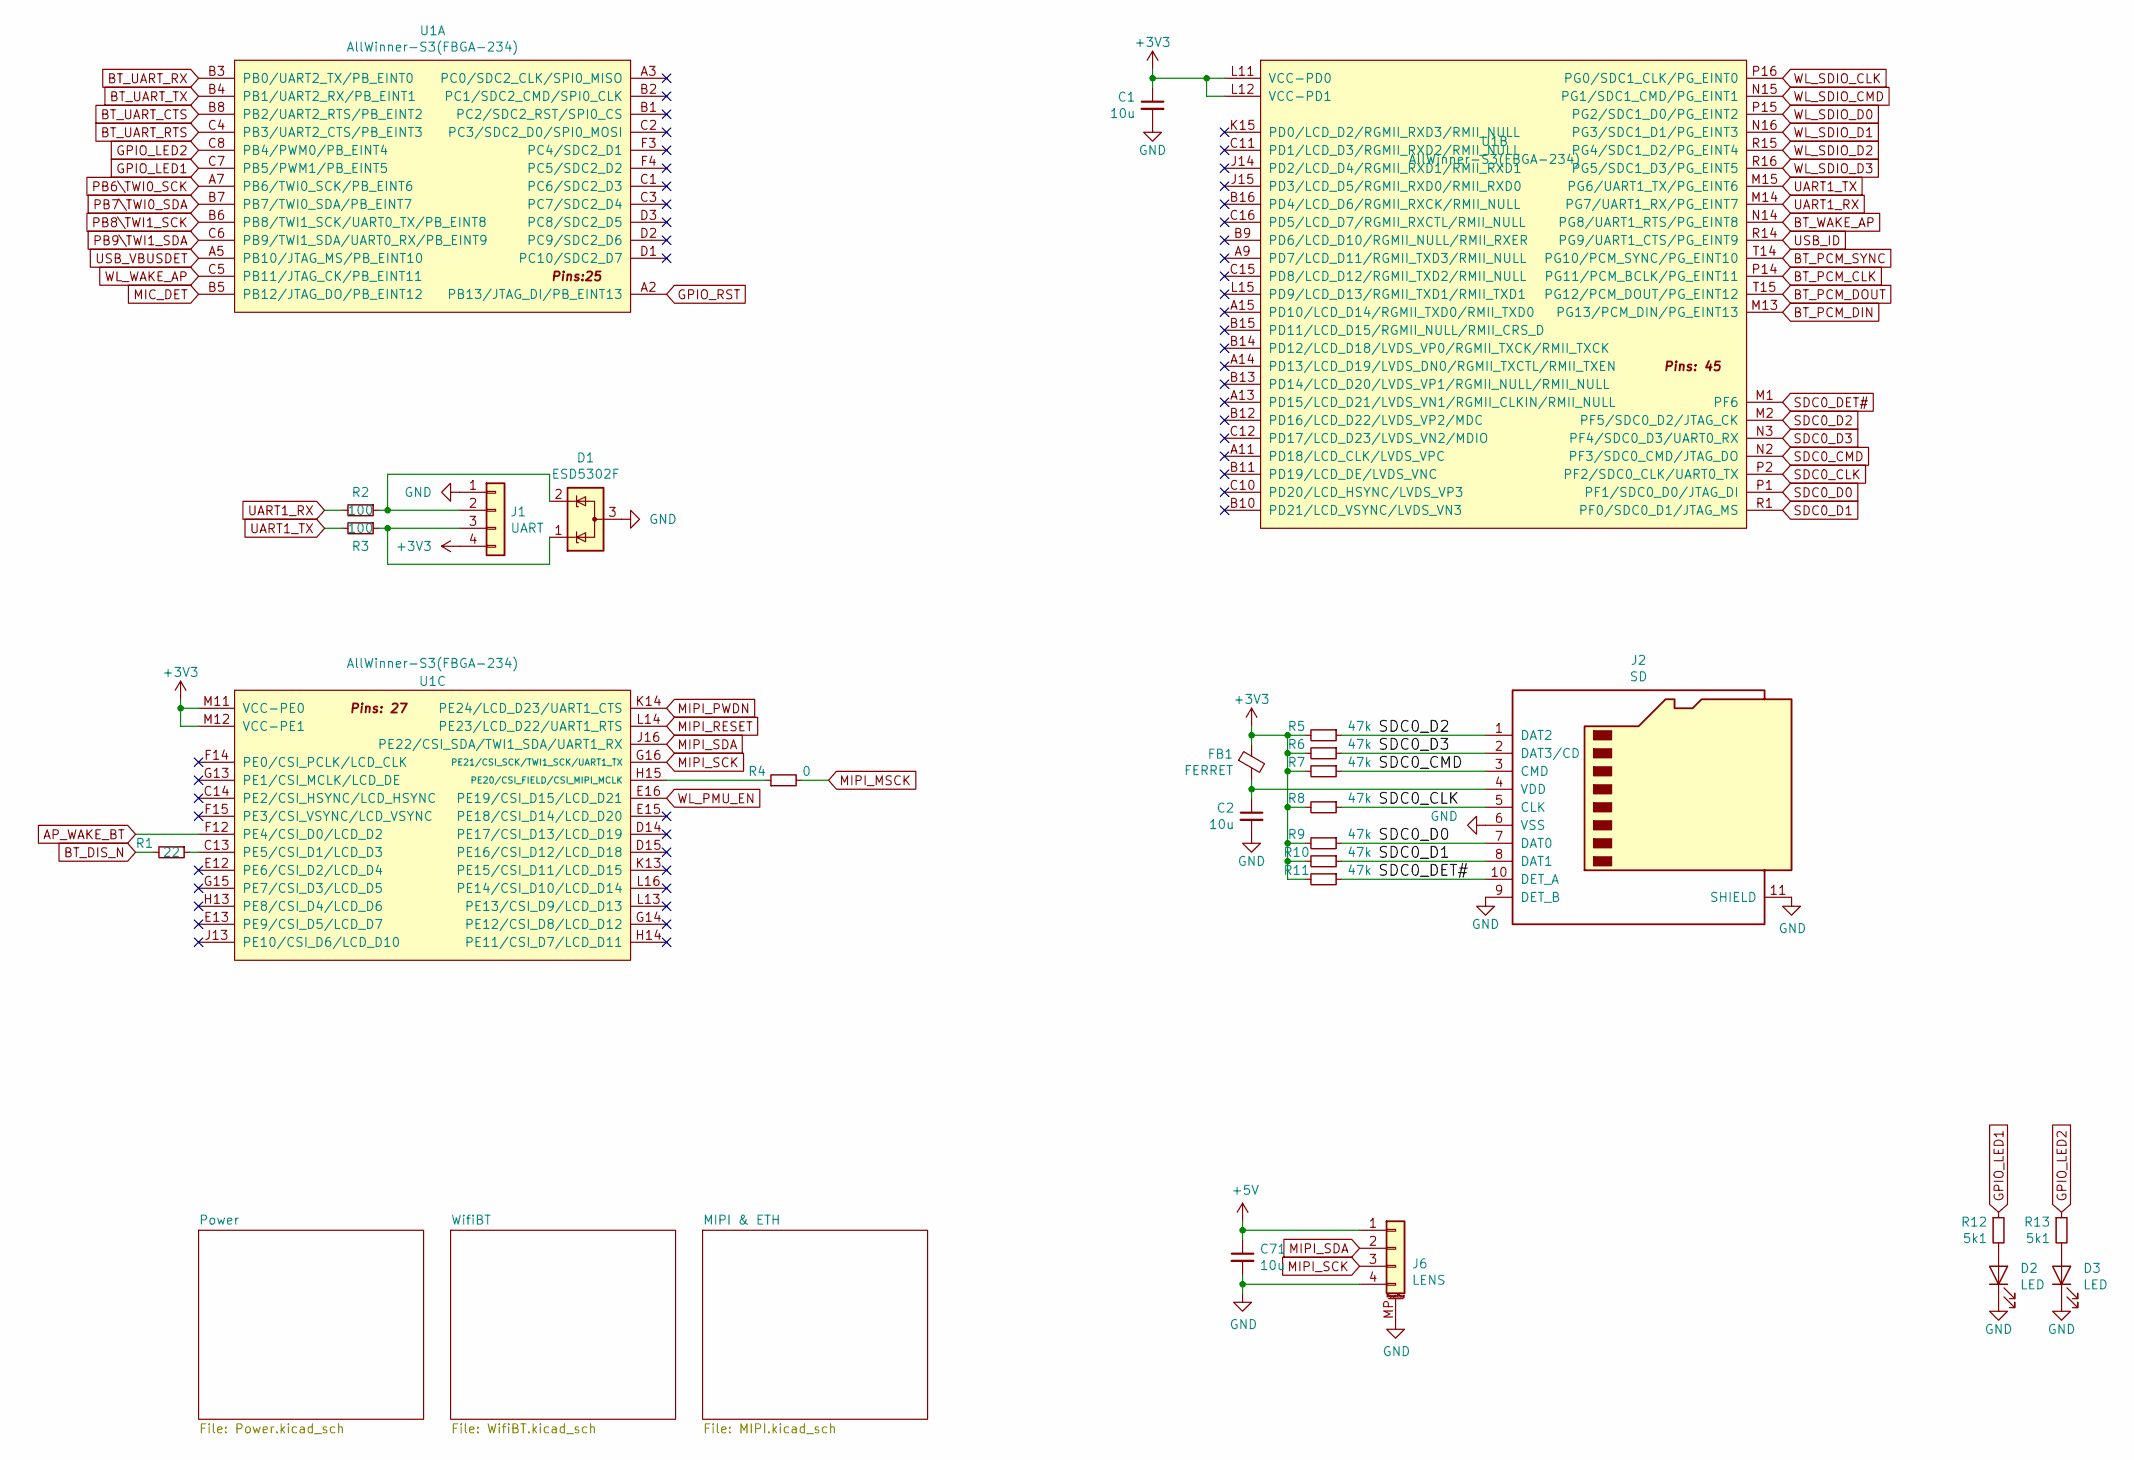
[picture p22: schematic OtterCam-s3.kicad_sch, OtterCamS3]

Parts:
C1, C2, C71: 10u; C_0603
D1: ESD5302F; SOT-23; LCSC C239643
D2, D3: LED; LED_0603_1608Metric
FB1: FERRET; R_0805
J1: UART; PinHeader_1x04_P2.00mm_Vertical_nosilk_center
J2: SD; microSD_HC_Hirose_DM3D-SF
J6: LENS; Molex_PicoBlade_53398-0471_1x04-1MP_P1.25mm_Vertical
R1: 22; R_0402
R2, R3: 100; R_0402
R4: 0; R_0402
R5, R6, R7, R8, R9, R10, R11: 47k; R_0402
R12, R13: 5k1; R_0402
U1: AllWinner-S3(FBGA-234); FBGA-234(Pitch-0.65mm_Pad-0.3mm_11x11x1.08mm)

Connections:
+3V3: C1.1, FB1.1, J1.4, R5.2, R6.2, R7.2, R8.2, R9.2, R10.2, R11.2, U1.L11 (VCC-PD0), U1.L12 (VCC-PD1), U1.M11 (VCC-PE0), U1.M12 (VCC-PE1); also elsewhere on the board
+5V: C71.1, J6.1; also elsewhere on the board
AP_WAKE_BT: U1.F12 (PE4/CSI_D0/LCD_D2); also elsewhere on the board
BT_DIS_N: R1.2; also elsewhere on the board
BT_PCM_CLK: U1.P14 (PG11/PCM_BCLK/PG_EINT11)
BT_PCM_DIN: U1.M13 (PG13/PCM_DIN/PG_EINT13)
BT_PCM_DOUT: U1.T15 (PG12/PCM_DOUT/PG_EINT12)
BT_PCM_SYNC: U1.T14 (PG10/PCM_SYNC/PG_EINT10)
BT_UART_CTS: U1.B8 (PB2/UART2_RTS/PB_EINT2); also elsewhere on the board
BT_UART_RTS: U1.C4 (PB3/UART2_CTS/PB_EINT3); also elsewhere on the board
BT_UART_RX: U1.B3 (PB0/UART2_TX/PB_EINT0); also elsewhere on the board
BT_UART_TX: U1.B4 (PB1/UART2_RX/PB_EINT1); also elsewhere on the board
BT_WAKE_AP: U1.N14 (PG8/UART1_RTS/PG_EINT8); also elsewhere on the board
GND: C1.2, C2.2, C71.2, D1.3 (A), D2.1 (K), D3.1 (K), J1.1, J2.6 (VSS), J2.9 (DET_B), J2.11 (SHIELD), J6.4, J6.MP (MountPin); also elsewhere on the board
GPIO_LED1: R12.1, U1.C7 (PB5/PWM1/PB_EINT5)
GPIO_LED2: R13.1, U1.C8 (PB4/PWM0/PB_EINT4)
GPIO_RST: U1.A2 (PB13/JTAG_DI/PB_EINT13); also elsewhere on the board
MIC_DET: U1.B5 (PB12/JTAG_DO/PB_EINT12)
MIPI_MSCK: R4.2; also elsewhere on the board
MIPI_PWDN: U1.K14 (PE24/LCD_D23/UART1_CTS)
MIPI_RESET: U1.L14 (PE23/LCD_D22/UART1_RTS); also elsewhere on the board
MIPI_SCK: J6.3, U1.G16 (PE21/CSI_SCK/TWI1_SCK/UART1_TX); also elsewhere on the board
MIPI_SDA: J6.2, U1.J16 (PE22/CSI_SDA/TWI1_SDA/UART1_RX); also elsewhere on the board
unnamed: C2.1, FB1.2, J2.4 (VDD)
unnamed: D1.1 (K), J1.3, R3.1
unnamed: D1.2 (K), J1.2, R2.1
unnamed: D2.2 (A), R12.2
unnamed: D3.2 (A), R13.2
unnamed: R1.1, U1.C13 (PE5/CSI_D1/LCD_D3)
unnamed: R4.1, U1.H15 (PE20/CSI_FIELD/CSI_MIPI_MCLK)
PB6\TWI0_SCK: U1.A7 (PB6/TWI0_SCK/PB_EINT6)
PB7\TWI0_SDA: U1.B7 (PB7/TWI0_SDA/PB_EINT7)
PB8\TWI1_SCK: U1.B6 (PB8/TWI1_SCK/UART0_TX/PB_EINT8)
PB9\TWI1_SDA: U1.C6 (PB9/TWI1_SDA/UART0_RX/PB_EINT9)
SDC0_CLK: J2.5 (CLK), R8.1, U1.P2 (PF2/SDC0_CLK/UART0_TX)
SDC0_CMD: J2.3 (CMD), R7.1, U1.N2 (PF3/SDC0_CMD/JTAG_DO)
SDC0_D0: J2.7 (DAT0), R9.1, U1.P1 (PF1/SDC0_D0/JTAG_DI)
SDC0_D1: J2.8 (DAT1), R10.1, U1.R1 (PF0/SDC0_D1/JTAG_MS)
SDC0_D2: J2.1 (DAT2), R5.1, U1.M2 (PF5/SDC0_D2/JTAG_CK)
SDC0_D3: J2.2 (DAT3/CD), R6.1, U1.N3 (PF4/SDC0_D3/UART0_RX)
SDC0_DET#: J2.10 (DET_A), R11.1, U1.M1 (PF6)
UART1_RX: R2.2, U1.M14 (PG7/UART1_RX/PG_EINT7)
UART1_TX: R3.2, U1.M15 (PG6/UART1_TX/PG_EINT6)
USB_ID: U1.R14 (PG9/UART1_CTS/PG_EINT9); also elsewhere on the board
USB_VBUSDET: U1.A5 (PB10/JTAG_MS/PB_EINT10)
WL_PMU_EN: U1.E16 (PE19/CSI_D15/LCD_D21); also elsewhere on the board
WL_SDIO_CLK: U1.P16 (PG0/SDC1_CLK/PG_EINT0); also elsewhere on the board
WL_SDIO_CMD: U1.N15 (PG1/SDC1_CMD/PG_EINT1); also elsewhere on the board
WL_SDIO_D0: U1.P15 (PG2/SDC1_D0/PG_EINT2); also elsewhere on the board
WL_SDIO_D1: U1.N16 (PG3/SDC1_D1/PG_EINT3); also elsewhere on the board
WL_SDIO_D2: U1.R15 (PG4/SDC1_D2/PG_EINT4); also elsewhere on the board
WL_SDIO_D3: U1.R16 (PG5/SDC1_D3/PG_EINT5); also elsewhere on the board
WL_WAKE_AP: U1.C5 (PB11/JTAG_CK/PB_EINT11); also elsewhere on the board

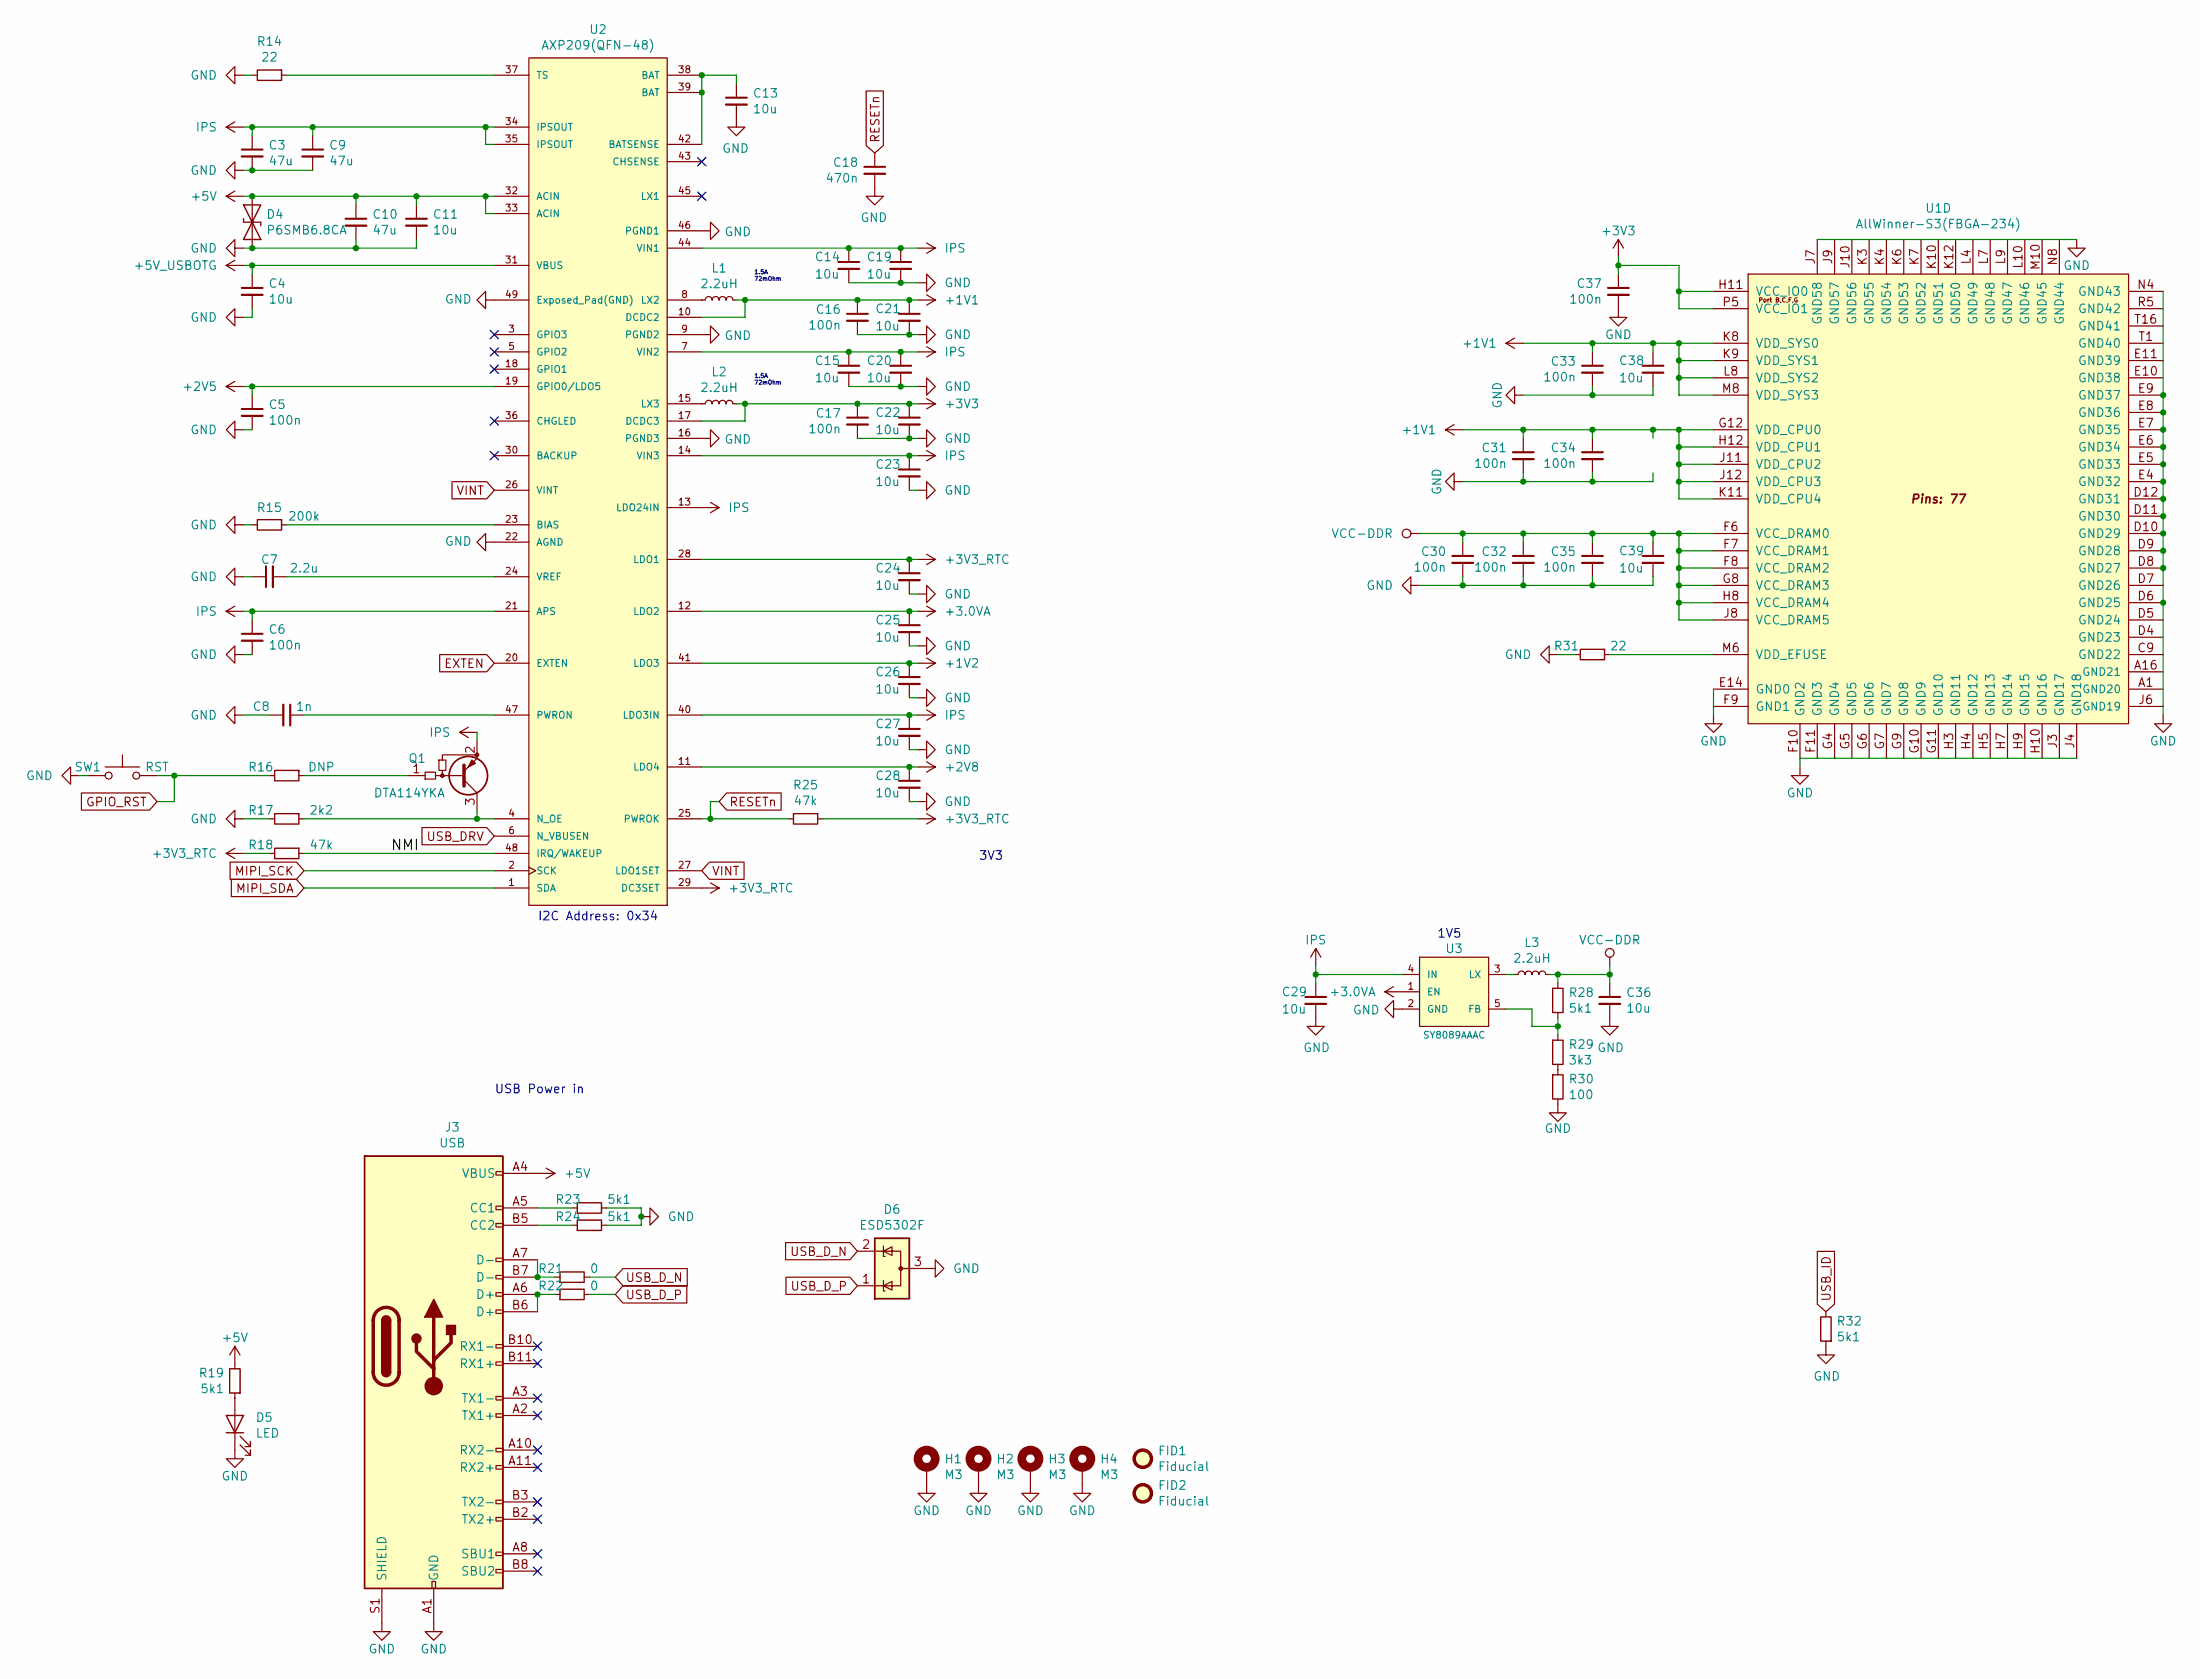
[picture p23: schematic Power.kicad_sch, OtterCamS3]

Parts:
C3, C9, C10: 47u; C_0805
C4, C11, C13, C14, C15, C19, C20, C21, C22, C23, C24, C25, C26, C27, C28, C29, C36, C38, C39: 10u; C_0603
C5, C6, C16, C17, C30, C31, C32, C33, C34, C35, C37: 100n; C_0402
C7: 2.2u; C_0603
C8: 1n; C_0402
C18: 470n; C_0402
D4: P6SMB6.8CA; D_SMB
D5: LED; LED_0603_1608Metric_Castellated
D6: ESD5302F; SOT-23; LCSC C239643
FID1, FID2: Fiducial; FID_1.52
H1, H2, H3, H4: M3; MountingHole_3mm_Pad_Via
J3: USB; 918-418K2022Y40004
L1, L2, L3: 2.2uH; L_Taiyo-Yuden_MD-3030; LCSC C167747
Q1: DTA114YKA; SOT-23
R14, R31: 22; R_0402
R15: 200k; R_0402
R16: DNP; R_0402
R17: 2k2; R_0402
R18, R25: 47k; R_0402
R19, R23, R24, R28, R32: 5k1; R_0402
R21, R22: 0; R_0402
R29: 3k3; R_0402
R30: 100; R_0402
SW1: RST; SW_SPST_PTS810
U1: AllWinner-S3(FBGA-234); FBGA-234(Pitch-0.65mm_Pad-0.3mm_11x11x1.08mm)
U2: AXP209(QFN-48); QFN-48-1EP_6x6mm_P0.4mm_EP4.05x4.05mm
U3: SY8089AAAC; SOT-23-5

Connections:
+1V1: C16.1, C21.1, C31.1, C33.1, C34.1, C38.1, L1.2, U1.G12 (VDD_CPU0), U1.H12 (VDD_CPU1), U1.J11 (VDD_CPU2), U1.J12 (VDD_CPU3), U1.K8 (VDD_SYS0), U1.K9 (VDD_SYS1), U1.K11 (VDD_CPU4), U1.L8 (VDD_SYS2), U1.M8 (VDD_SYS3), U2.10 (DCDC2); also elsewhere on the board
+1V2: C26.1, U2.41 (LDO3)
+2V5: C5.1, U2.19 (GPIO0/LDO5)
+2V8: C28.1, U2.11 (LDO4)
+3.0VA: C25.1, U2.12 (LDO2), U3.1 (EN); also elsewhere on the board
+3.3V_RTC: C24.1, R18.2, R25.1, U2.28 (LDO1), U2.29 (DC3SET); also elsewhere on the board
+3V3: C17.1, C22.1, C37.1, L2.2, U1.H11 (VCC_IO0), U1.P5 (VCC_IO1), U2.17 (DCDC3); also elsewhere on the board
+5V: C10.1, C11.1, D4.1 (A1), J3.A4 (VBUS), J3.A9 (VBUS), J3.B4 (VBUS), J3.B9 (VBUS), R19.2, U2.32 (ACIN), U2.33 (ACIN); also elsewhere on the board
+5V_USBOTG: C4.1, U2.31 (VBUS)
/Power/NMI: R18.1, U2.48 (IRQ/WAKEUP)
EXTEN: U2.20 (EXTEN)
GND: C3.2, C4.2, C5.2, C6.2, C7.1, C8.2, C9.2, C10.2, C11.2, C13.2, C14.2, C15.2, C16.2, C17.2, C18.2, C19.2, C20.2, C21.2, C22.2, C23.2, C24.2, C25.2, C26.2, C27.2, C28.2, C29.2, C30.2, C31.2, C32.2, C33.2, C34.2, C35.2, C36.2, C37.2, C38.2, C39.2, D4.2 (A2), D5.1 (K), D6.3 (A), H1.1, H2.1, H3.1, H4.1, J3.A1 (GND), J3.A12 (GND), J3.B1 (GND), J3.B12 (GND), J3.S1 (SHIELD), R14.2, R15.2, R17.2, R23.2, R24.2, R30.2, R31.2, R32.1, SW1.1, U1.A1 (GND20), U1.A16 (GND21), U1.C9 (GND22), U1.D4 (GND23), U1.D5 (GND24), U1.D6 (GND25), U1.D7 (GND26), U1.D8 (GND27), U1.D9 (GND28), U1.D10 (GND29), U1.D11 (GND30), U1.D12 (GND31), U1.E4 (GND32), U1.E5 (GND33), U1.E6 (GND34), U1.E7 (GND35), U1.E8 (GND36), U1.E9 (GND37), U1.E10 (GND38), U1.E11 (GND39), U1.E14 (GND0), U1.F9 (GND1), U1.F10 (GND2), U1.F11 (GND3), U1.G4 (GND4), U1.G5 (GND5), U1.G6 (GND6), U1.G7 (GND7), U1.G9 (GND8), U1.G10 (GND9), U1.G11 (GND10), U1.H3 (GND11), U1.H4 (GND12), U1.H5 (GND13), U1.H7 (GND14), U1.H9 (GND15), U1.H10 (GND16), U1.J3 (GND17), U1.J4 (GND18), U1.J6 (GND19), U1.J7 (GND58), U1.J9 (GND57), U1.J10 (GND56), U1.K3 (GND55), U1.K4 (GND54), U1.K6 (GND53), U1.K7 (GND52), U1.K10 (GND51), U1.K12 (GND50), U1.L4 (GND49), U1.L7 (GND48), U1.L9 (GND47), U1.L10 (GND46), U1.M10 (GND45), U1.N4 (GND43), U1.N8 (GND44), U1.R5 (GND42), U1.T1 (GND40), U1.T16 (GND41), U2.9 (PGND2), U2.16 (PGND3), U2.22 (AGND), U2.46 (PGND1), U2.49 (Exposed_Pad(GND)), U3.2 (GND); also elsewhere on the board
GPIO_RST: R16.2, SW1.2; also elsewhere on the board
IPS: C3.1, C6.1, C9.1, C14.1, C15.1, C19.1, C20.1, C23.1, C27.1, C29.1, Q1.2 (E), U2.7 (VIN2), U2.13 (LDO24IN), U2.14 (VIN3), U2.21 (APS), U2.34 (IPSOUT), U2.35 (IPSOUT), U2.40 (LDO3IN), U2.44 (VIN1), U3.4 (IN)
MIPI_SCK: U2.2 (SCK); also elsewhere on the board
MIPI_SDA: U2.1 (SDA); also elsewhere on the board
unnamed: C7.2, U2.24 (VREF)
unnamed: C8.1, U2.47 (PWRON)
unnamed: C13.1, U2.38 (BAT), U2.39 (BAT), U2.42 (BATSENSE)
unnamed: D5.2 (A), R19.1
unnamed: J3.A5 (CC1), R23.1
unnamed: J3.A6 (D+), J3.B6 (D+), R22.1
unnamed: J3.A7 (D-), J3.B7 (D-), R21.1
unnamed: J3.B5 (CC2), R24.1
unnamed: L1.1, U2.8 (LX2)
unnamed: L2.1, U2.15 (LX3)
unnamed: L3.1, U3.3 (LX)
unnamed: Q1.1 (B), R16.1
unnamed: Q1.3 (C), R17.1, U2.4 (N_OE)
unnamed: R14.1, U2.37 (TS)
unnamed: R15.1, U2.23 (BIAS)
unnamed: R28.2, R29.1, U3.5 (FB)
unnamed: R29.2, R30.1
unnamed: R31.1, U1.M6 (VDD_EFUSE)
RESETn: C18.1, R25.2, U2.25 (PWROK); also elsewhere on the board
USB_DRV: U2.6 (N_VBUSEN)
USB_D_N: D6.2 (K), R21.2; also elsewhere on the board
USB_D_P: D6.1 (K), R22.2; also elsewhere on the board
USB_ID: R32.2; also elsewhere on the board
VCC-DDR: C30.1, C32.1, C35.1, C36.1, C39.1, L3.2, R28.1, U1.F6 (VCC_DRAM0), U1.F7 (VCC_DRAM1), U1.F8 (VCC_DRAM2), U1.G8 (VCC_DRAM3), U1.H8 (VCC_DRAM4), U1.J8 (VCC_DRAM5); also elsewhere on the board
VINT: U2.26 (VINT), U2.27 (LDO1SET)

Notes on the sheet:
1.5A 72mOhm
1V5
3V3
USB Power in
I2C Address: 0x34

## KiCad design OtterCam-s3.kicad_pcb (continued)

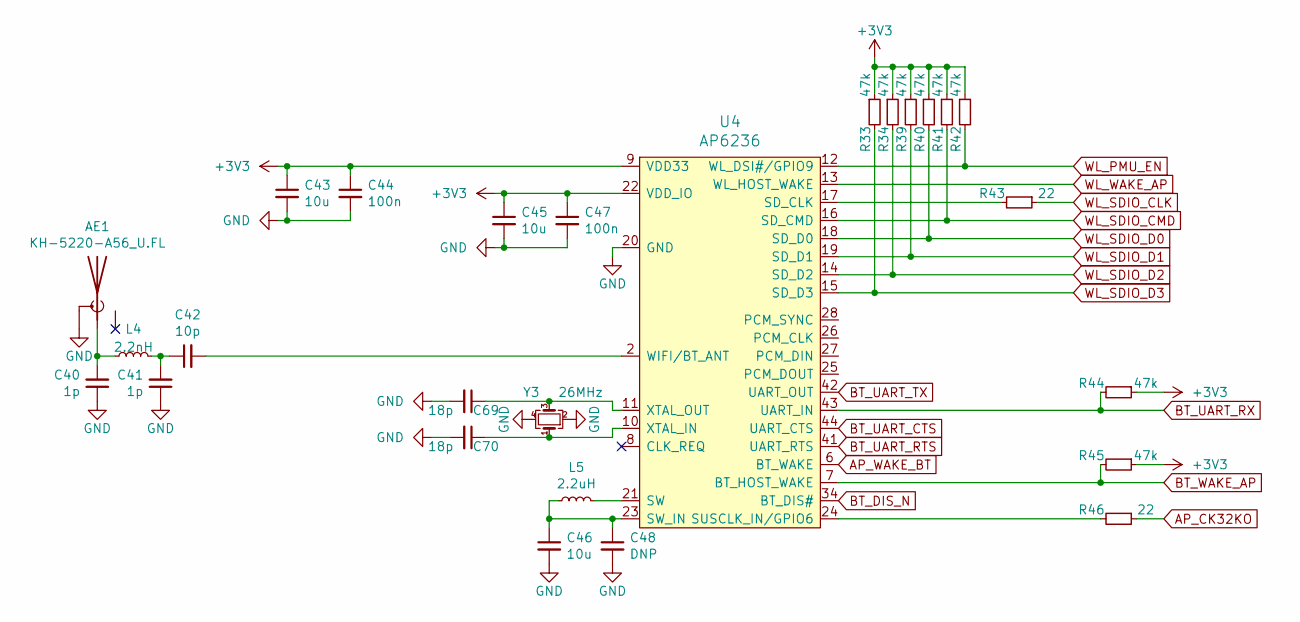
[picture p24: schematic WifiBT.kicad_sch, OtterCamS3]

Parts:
AE1: KH-5220-A56_U.FL; U.FL_Hirose_U.FL-R-SMT-1_Vertical
C40, C41: 1p; C_0402
C42: 10p; C_0402
C43, C45, C46: 10u; C_0603
C44, C47: 100n; C_0402
C48: DNP; C_0402
C69, C70: 18p; C_0402
L4: 2.2nH; L_0402
L5: 2.2uH; L_Taiyo-Yuden_MD-3030; LCSC C167747
R33, R34, R39, R40, R41, R42, R44, R45: 47k; R_0402
R43, R46: 22; R_0402
U4: AP6236; LGA_44_12x12mm_0.9mm
Y3: 26MHz; Oscillator_3225

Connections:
+3V3: C43.1, C44.1, C45.1, C47.1, R33.1, R34.1, R39.1, R40.1, R41.1, R42.1, R44.1, R45.1, U4.9 (VDD33), U4.22 (VDD_IO); also elsewhere on the board
AP_CK32KO: R46.1; also elsewhere on the board
AP_WAKE_BT: U4.6 (BT_WAKE); also elsewhere on the board
BT_DIS_N: U4.34 (BT_DIS#); also elsewhere on the board
BT_UART_CTS: U4.44 (UART_CTS); also elsewhere on the board
BT_UART_RTS: U4.41 (UART_RTS); also elsewhere on the board
BT_UART_RX: R44.2, U4.43 (UART_IN); also elsewhere on the board
BT_UART_TX: U4.42 (UART_OUT); also elsewhere on the board
BT_WAKE_AP: R45.2, U4.7 (BT_HOST_WAKE); also elsewhere on the board
GND: AE1.2 (Shield), C40.1, C41.1, C43.2, C44.2, C45.2, C46.2, C47.2, C48.2, C69.2, C70.2, U4.1 (GND), U4.20 (GND), U4.31 (GND), U4.33 (GND), U4.36 (GND), Y3.2, Y3.4; also elsewhere on the board
unnamed: AE1.1 (A), C40.2, L4.1
unnamed: C41.2, C42.1, L4.2
unnamed: C42.2, U4.2 (WIFI/BT_ANT)
unnamed: C46.1, C48.1, L5.1, U4.23 (SW_IN)
unnamed: C69.1, U4.11 (XTAL_OUT), Y3.3
unnamed: C70.1, U4.10 (XTAL_IN), Y3.1
unnamed: L5.2, U4.21 (SW)
unnamed: R43.2, U4.17 (SD_CLK)
unnamed: R46.2, U4.24 (SUSCLK_IN/GPIO6)
WL_PMU_EN: R42.2, U4.12 (WL_DSI#/GPIO9); also elsewhere on the board
WL_SDIO_CLK: R43.1; also elsewhere on the board
WL_SDIO_CMD: R41.2, U4.16 (SD_CMD); also elsewhere on the board
WL_SDIO_D0: R40.2, U4.18 (SD_D0); also elsewhere on the board
WL_SDIO_D1: R39.2, U4.19 (SD_D1); also elsewhere on the board
WL_SDIO_D2: R34.2, U4.14 (SD_D2); also elsewhere on the board
WL_SDIO_D3: R33.2, U4.15 (SD_D3); also elsewhere on the board
WL_WAKE_AP: U4.13 (WL_HOST_WAKE); also elsewhere on the board

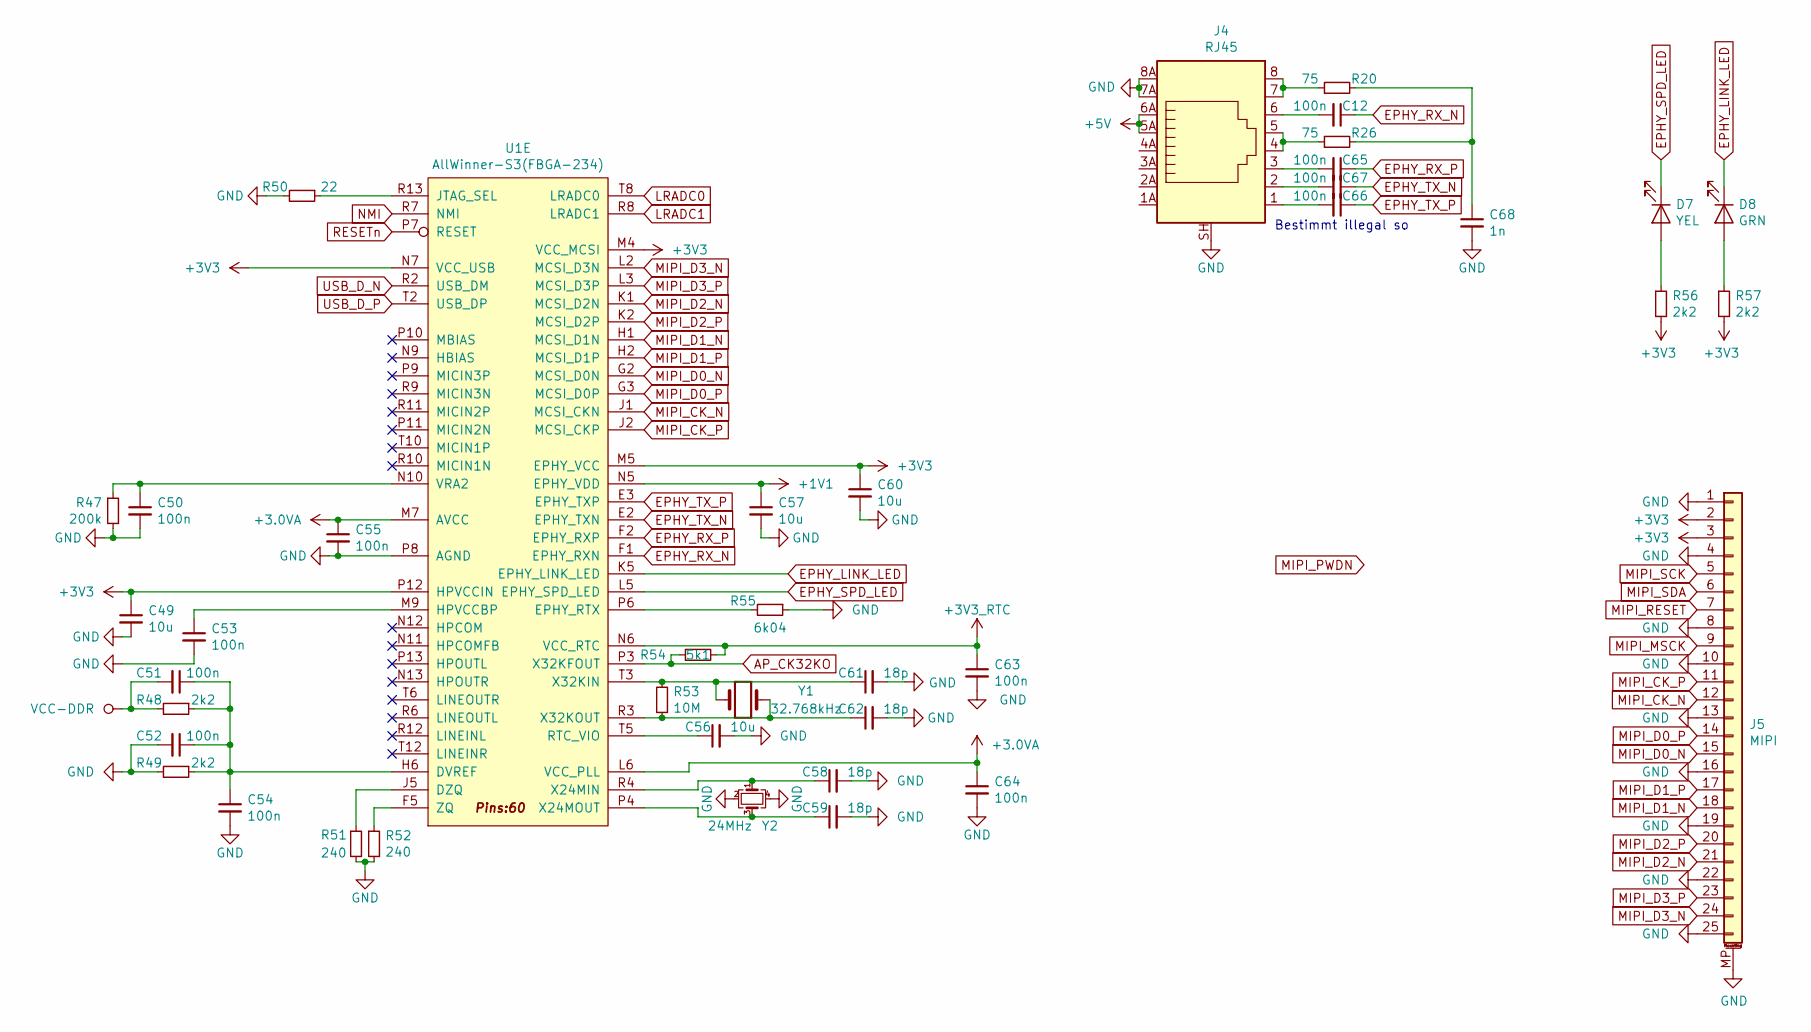
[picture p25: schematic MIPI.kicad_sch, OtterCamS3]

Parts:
C12, C65, C66, C67: 100n; C_0805
C49, C56, C57, C60: 10u; C_0603
C50, C51, C52, C53, C54, C55, C63, C64: 100n; C_0402
C58, C59, C61, C62: 18p; C_0402
C68: 1n; C_0805
D7: YEL; LED_0603_1608Metric_Castellated
D8: GRN; LED_0603_1608Metric_Castellated
J4: RJ45; 1-338088-3
J5: MIPI; FH35C-25S
R20, R26: 75; R_0402
R47: 200k; R_0402
R48, R49, R56, R57: 2k2; R_0402
R50: 22; R_0402
R51, R52: 240; R_0402
R53: 10M; R_0402
R54: 5k1; R_0402
R55: 6k04; R_0402
U1: AllWinner-S3(FBGA-234); FBGA-234(Pitch-0.65mm_Pad-0.3mm_11x11x1.08mm)
Y1: 32.768kHz; Crystal_SMD_3215-2Pin_3.2x1.5mm
Y2: 24MHz; Oscillator_3225

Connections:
+1V1: C57.1, U1.N5 (EPHY_VDD); also elsewhere on the board
+3.0VA: C55.1, C64.1, U1.L6 (VCC_PLL), U1.M7 (AVCC); also elsewhere on the board
+3.3V_RTC: C63.1, R54.2, U1.N6 (VCC_RTC); also elsewhere on the board
+3V3: C49.1, C60.1, J5.2, J5.3, R56.2, R57.2, U1.M4 (VCC_MCSI), U1.M5 (EPHY_VCC), U1.N7 (VCC_USB), U1.P12 (HPVCCIN); also elsewhere on the board
+5V: J4.5A, J4.6A; also elsewhere on the board
AP_CK32KO: R54.1, U1.P3 (X32KFOUT); also elsewhere on the board
EPHY_LINK_LED: D8.1 (K), U1.K5 (EPHY_LINK_LED)
EPHY_RX_N: C12.1, U1.F1 (EPHY_RXN)
EPHY_RX_P: C65.1, U1.F2 (EPHY_RXP)
EPHY_SPD_LED: D7.1 (K), U1.L5 (EPHY_SPD_LED)
EPHY_TX_N: C67.1, U1.E2 (EPHY_TXN)
EPHY_TX_P: C66.1, U1.E3 (EPHY_TXP)
GND: C49.2, C50.2, C52.2, C53.2, C54.2, C55.2, C56.2, C57.2, C58.2, C59.2, C60.2, C61.2, C62.2, C63.2, C64.2, C68.2, J4.7A, J4.8A, J4.SH, J5.1, J5.4, J5.8, J5.10, J5.13, J5.16, J5.19, J5.22, J5.25, J5.MP (MountPin), R47.2, R49.2, R50.2, R51.2, R52.2, R55.1, U1.P8 (AGND), Y2.2, Y2.4; also elsewhere on the board
LRADC0: U1.T8 (LRADC0)
LRADC1: U1.R8 (LRADC1)
MIPI_CK_N: J5.12, U1.J1 (MCSI_CKN)
MIPI_CK_P: J5.11, U1.J2 (MCSI_CKP)
MIPI_D0_N: J5.15, U1.G2 (MCSI_D0N)
MIPI_D0_P: J5.14, U1.G3 (MCSI_D0P)
MIPI_D1_N: J5.18, U1.H1 (MCSI_D1N)
MIPI_D1_P: J5.17, U1.H2 (MCSI_D1P)
MIPI_D2_N: J5.21, U1.K1 (MCSI_D2N)
MIPI_D2_P: J5.20, U1.K2 (MCSI_D2P)
MIPI_D3_N: J5.24, U1.L2 (MCSI_D3N)
MIPI_D3_P: J5.23, U1.L3 (MCSI_D3P)
MIPI_MSCK: J5.9; also elsewhere on the board
MIPI_RESET: J5.7; also elsewhere on the board
MIPI_SCK: J5.5; also elsewhere on the board
MIPI_SDA: J5.6; also elsewhere on the board
NMI: U1.R7 (NMI)
unnamed: C12.2, J4.6
unnamed: C50.1, R47.1, U1.N10 (VRA2)
unnamed: C51.1, C52.1, C54.1, R48.1, R49.1, U1.H6 (DVREF)
unnamed: C53.1, U1.M9 (HPVCCBP)
unnamed: C56.1, U1.T5 (RTC_VIO)
unnamed: C58.1, U1.R4 (X24MIN), Y2.1
unnamed: C59.1, U1.P4 (X24MOUT), Y2.3
unnamed: C61.1, R53.2, U1.T3 (X32KIN), Y1.1
unnamed: C62.1, R53.1, U1.R3 (X32KOUT), Y1.2
unnamed: C65.2, J4.3
unnamed: C66.2, J4.1
unnamed: C67.2, J4.2
unnamed: C68.1, R20.2, R26.2
unnamed: D7.2 (A), R56.1
unnamed: D8.2 (A), R57.1
unnamed: J4.4, J4.5, R26.1
unnamed: J4.7, J4.8, R20.1
unnamed: R50.1, U1.R13 (JTAG_SEL)
unnamed: R51.1, U1.J5 (DZQ)
unnamed: R52.1, U1.F5 (ZQ)
unnamed: R55.2, U1.P6 (EPHY_RTX)
RESETn: U1.P7 (RESET); also elsewhere on the board
USB_D_N: U1.R2 (USB_DM); also elsewhere on the board
USB_D_P: U1.T2 (USB_DP); also elsewhere on the board
VCC-DDR: C51.2, R48.2; also elsewhere on the board

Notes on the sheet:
Bestimmt illegal so

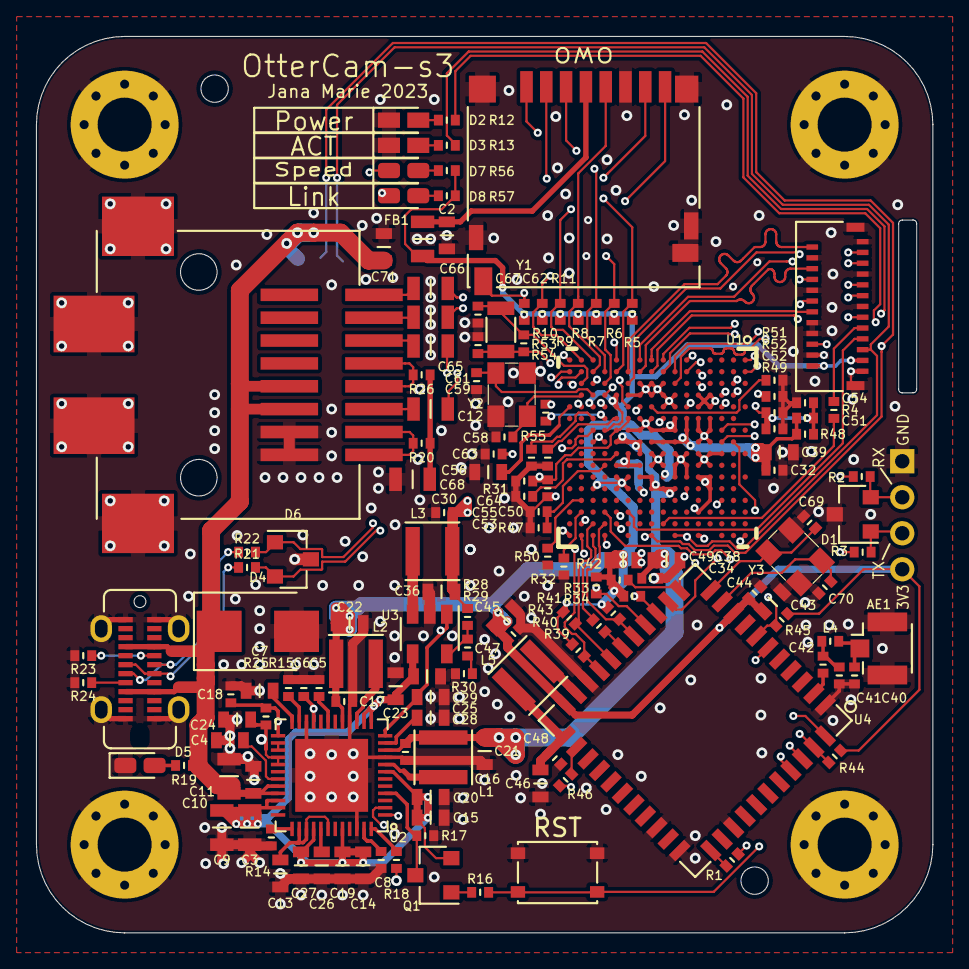
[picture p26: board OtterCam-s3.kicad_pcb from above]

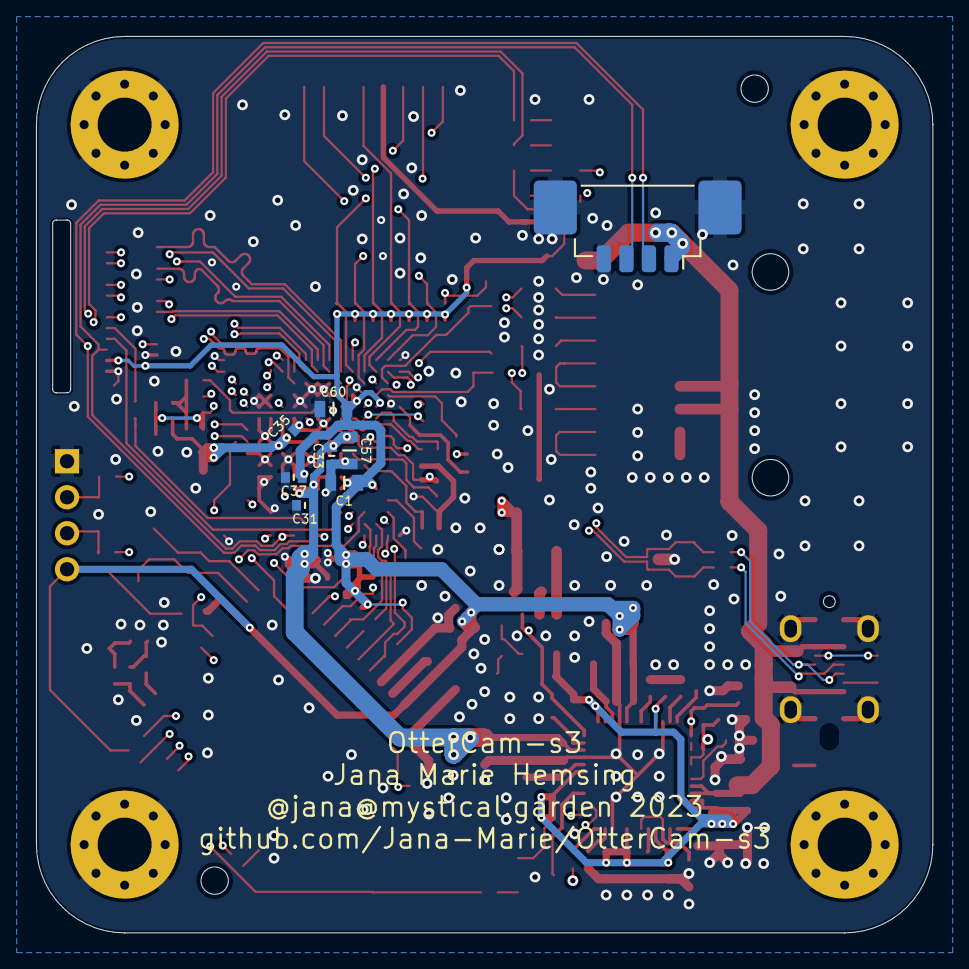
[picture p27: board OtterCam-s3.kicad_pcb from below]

Board: 4 copper layers, 49.8 x 49.8 mm, 159 parts (12 on the bottom side), 121 nets.

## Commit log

2021-04-28 updated files
    [BOM_v2.1.csv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]
2021-04-28 removed old files
    [BOM_v2.1.csv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]
2021-04-28 routed mipi, eth and sdio
    [OtterCam-s3.kicad_pcb]
2021-04-28 routed all high speed signals
    [OtterCam-s3.kicad_pcb]
2021-05-02 mostly routed
    [MIPI.sch, OtterCam-s3.kicad_pcb, OtterCam-s3.sch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]
2021-05-02 routing finished
    [MIPI.sch, OtterCam-s3.kicad_pcb, Power.sch]
2021-05-09 sensor board v1.0 mostly routed
    [sensor_v1.0.kicad_pcb, sensor_v1.0.sch, sensor_v1.0.step]
2021-05-09 routing 100%
    [sensor_v1.0.kicad_pcb, sensor_v1.0.sch]
2021-05-09 new 3d files
    [OtterCam-s3.kicad_pcb]
2021-10-11 fixed MIPI pinout, added pullups, fixed silkscreen
    [sensor_v1.0.kicad_pcb, sensor_v1.0.sch]
2021-10-11 exported gerber, moved old gerber
    [sensor_v1.0-B_Cu.gbl, sensor_v1.0-B_Mask.gbs, sensor_v1.0-B_Paste.gbp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]
2021-10-11 added all gerber
    [BOM.csv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]
2021-10-11 renamed folder
    [sensor.kicad_pcb, sensor.sch, sensor.step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]
2021-10-11 renamed lens folder
    [lensmount-v1.0-B_Cu.gbl, lensmount-v1.0-B_Mask.gbs, lensmount-v1.0-B_Paste.gbp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]
2021-10-11 added schematic print
2021-10-11 fixed silkscreen
    [OtterCam-s3-B_Cu.gbl, OtterCam-s3-B_Mask.gbs, OtterCam-s3-B_Paste.gbp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]
2022-01-18 updated to kicad 6
    [Audio.sch, BOM.csv, MIPI.kicad_sch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]
2023-02-02 updated hw files
    [MIPI.kicad_sch, OtterCam-s3.kicad_sch, Power.kicad_sch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]
2023-02-02 added CAD readme
2023-02-02 added SCAD files
    [OtterCamS3.scad]
2023-02-02 added case stl files
    [c_mount.stl, cap_b.stl, cs_mount.stl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]
2023-02-02 removed files
    [BOM.csv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]
2023-02-02 removed binary files
    [c_mount.stl, cap_b.stl, cs_mount.stl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]
2023-02-02 updated schematic files
    [MIPI.kicad_sch, OtterCam-s3.kicad_sch, Power.kicad_sch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]
2023-02-02 updated project and board files
    [OtterCam-s3.kicad_pcb]
2023-02-02 updated sensor board
    [sensor.kicad_pcb, sensor.kicad_sch]
2023-02-02 updated lensmount
    [lensmount.kicad_pcb, lensmount.kicad_sch]
2023-02-02 removed binaries and old files
    [lensmount-B_Cu.gbl, lensmount-B_Mask.gbs, lensmount-B_Paste.gbp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]
2023-02-02 updated c and cs mount
    [OtterCamS3.scad]
